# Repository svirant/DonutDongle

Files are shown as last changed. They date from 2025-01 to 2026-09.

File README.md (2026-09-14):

# Donut Dongle

**Arduino Nano based hub that connects your digital and analog console switching setup with the RetroTink 4K and/or RetroTink 5x / OSSC for Auto Profile switching** </br>

The Donut Dongle connects to a switch in a way that allows it to see which port is active. When a console powers on (auto-switching) or an input is manually selected, the Donut Dongle sends a serial command to the RetroTink 4k (or IR signal to the RT5x, OSSC) telling it to load a profile. For the RT4K, the profiles can either be defined as remote profiles; those configured in the menu for the remote buttons. Or they can be SVS profiles which are configured on the RT4K's SDcard. <br />

For details, refer to the ["How to Use"](https://github.com/svirant/DonutDongle/tree/main/README.md#how-to-use) section below.

> [!TIP]
> If DIY is not your thing. I have assembled versions for gScart/gComp and MT-VIKI/TESmart/Extron/db9 available in my [Ko-fi](https://ko-fi.com/donutswdad/shop) shop.
</br>

> [!NOTE]
> *NEW* version allows:
>   - **Alternate SVS Profile System** - allows a different set of profiles to load. Explained in the ["New IR Remote Control functionality"](https://github.com/svirant/DonutDongle#new-ir-remote-control-functionality) section below.
>   - **Fallback** - feature that allows a switch that reports having no active inputs to change profiles over to one that does.
>   - **MT-VIKI Disconnection Detection** - when an input is powered off and on, the profile is resent.
>     - **Disable MT-VIKI beeping by pressing the "#" button on its remote.**
>   - **front case buttons/remote NOW change profiles on the MT-VIKI HDMI switch.** Thanks to [Arthrimus](https://scalablevideoswitch.com/)! 
>   - **auto-switching on Extron Matrix switchers** that support DSVP. Works with RGBS/HV and HDMI/DVI signal types.
>   - **Support for older Extron Crosspoint (non plus) matrix switchers**
> <br />
> 
> <br /> Use the follow Options to enable:
> ```
> #define automatrixSW1 true  // set true for auto matrix switching on "SW1" port
> #define automatrixSW2 false // set true for auto matrix switching on "SW2" port
>
> uint8_t const ExtronVideoOutputPortSW1 = 1; // For non "Plus" Extron Matrix models, must specify video output port that connects to RT4K
> uint8_t const ExtronVideoOutputPortSW2 = 1;
> 
> uint8_t const vinMatrix[65] = {0,  // MATRIX switchers  // When auto matrix mode is enabled: (automatrixSW1 / SW2 defined above)
>                                                        // set to 0 for the auto switched input to tie to all outputs
>                                                        // set to 1 for the auto switched input to trigger a Preset
>                                                        // set to 2 for the auto switched input to tie to "ExtronVideoOutputPortSW1" / "ExtronVideoOutputPortSW2"
>                                                        //
>                                                        // For option 1, set the following inputs to the desired Preset #
>                                                        // (by default each input # is set to the same corresponding Preset #)
>                                                       
> ```
<br />

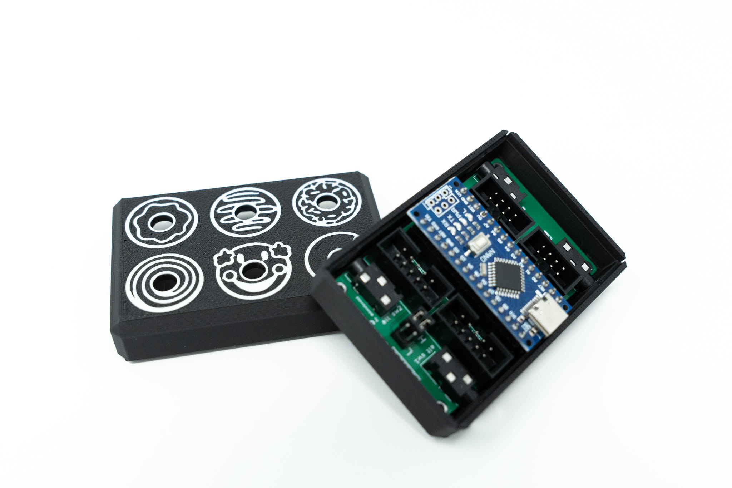
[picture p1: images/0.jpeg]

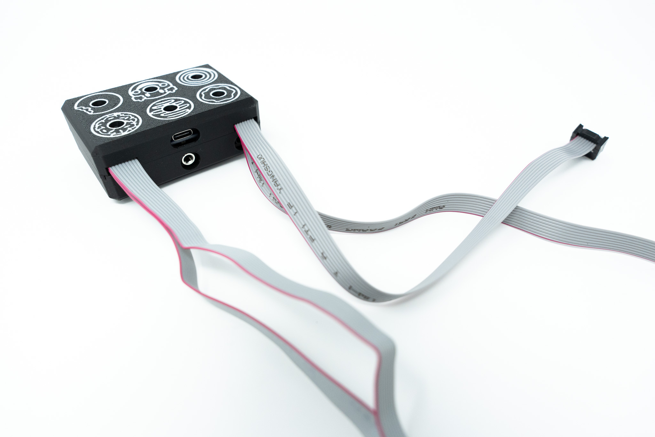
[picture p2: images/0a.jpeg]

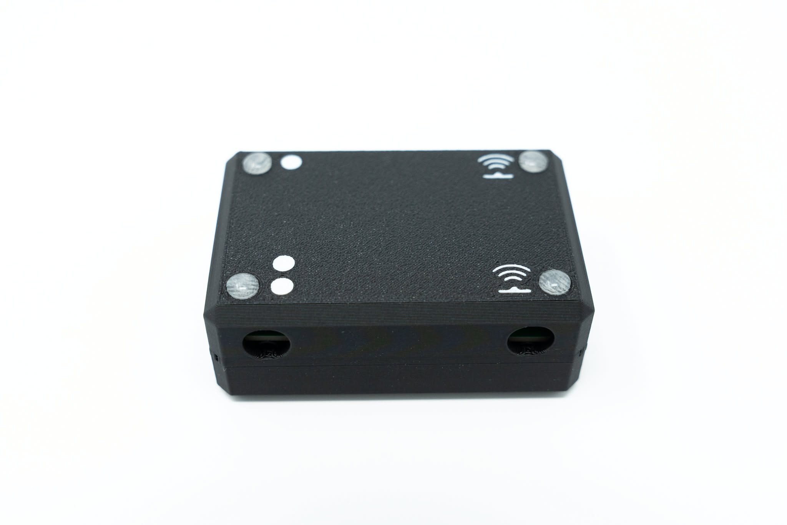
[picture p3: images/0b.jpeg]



### [More Images...](https://photos.sixteenbit.app/share/KXUwNPO2uvjenoCdj3gsQnEMd4q5h4ymUv-0fc8PItIhjA8JXHlVgPDeFnTRXM76KPM)

<br />

# Thanks to 
 - [Justin Peacock](https://byjustin.me/) for the amazing case design
 - HerraAAV3 from the RetroTink discord for the VGA Adapter case design
 - [Mike Chi](https://retrotink.com) for help with the open drain serial bits
 - [@niquallis](https://x.com/niquallis), [@UstSte](https://x.com/UstSte), and last but not least [Aru](https://x.com/CielFricker249) for beta testing

<br />

# Supported Switches
(current list, but not limited to)
| **Switch** | Supported | Notes |
| --- | --- |--- |
| MT-VIKI 8 port HDMI | yes, confirmed first hand. RT4K remote can also change inputs and profiles.  | Front case buttons and included IR remote also change profiles! **Disable MT-VIKI beeping by pressing the "#" button on its remote.** |
| TESmart 16x1 HDMI  | yes, confirmed first hand  | RT4K remote can also change inputs and profiles. |
| TESmart 8x1 HDMI  | unconfirmed, but should work, let me know! ||
| gSCARTsw / gCOMPsw | **version 5.x** confirmed by [@niquallis](https://x.com/niquallis) and [@UstSte](https://x.com/UstSte), thanks so much for your help! | Manual input selection works too! |
| Extron RGBHV sw6  | yes, confirmed first hand  | |
| Extron DXP 88 | yes, confirmed first hand | Auto-switching can be enabled in "Options" section of .ino.  Works with Presets. On SW1, Preset 1 is S1_ profile. On SW2, Preset 1 is S101_ profile, etc. <br><br>Power up the switch before connecting the DonutHole. |
| Extron CrossPoint, MVX, etc | yes, confirmed by other users | Auto-switching can be enabled for switches that supports DSVP and are RGBS/HDMI/DVI signal types. By default, works with Presets as shown in the Note above. |
| Extron CrossPoint E-series  | yes, works with Presets and Input changes | Must set ExtronVideoOutputPortSW1 / SW2 variable to output connected to RT4K |
| Extron SW4 VGA Ars | yes, confirmed by "Nobody" on the RT4K Discord |
| Otaku Games Scart 10 | Jumper moved to "L" and with required [mod](https://github.com/svirant/RT4k_HD15_serial_control/tree/main/Otaku%20Games%20Scart%20Switch) , **SVS=0; must also be set in the Otaku .ino for the DD to respond** | modded switch works on its own, but connecting through the DD is mostly useful if your Otaku mod doesn't include the buffer IC |

<br />

# Connections
  - Connect 4 switches Total
    - 2x gscart/gcomp
    - 2x Extron, 2x TESmart, or 1 of each
  - 1x usb-c port for power/programming (on Arduino Nano)
  - 1x 3.5mm "TX OUT to Retrotink 4K VGA adapter" port
  - 1x IR Emitter (required for OSSC, RT5x (RT5x must be on firmware version 3.7 or higher))
  - 1x IR Receiver (optional for better reception and IR remote customizations)
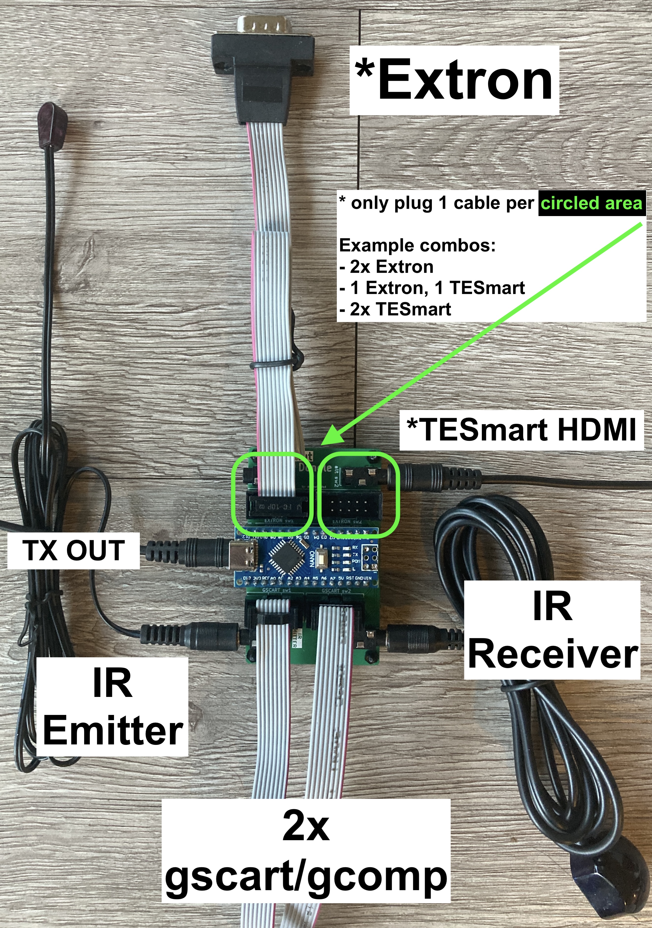
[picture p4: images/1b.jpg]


<br /><br />

# Layout Example
 - **TESmart 16x1 HDMI switch & 2x gSCART/gCOMP**
    - **VGA Passthrough adapter**
    - **TESmart adapter**
    - **gScart EXT pushpin adapter**


<br />
<br />

 - **Case closed**
   - **ribbon cables fold over and come out slots in the back of case**

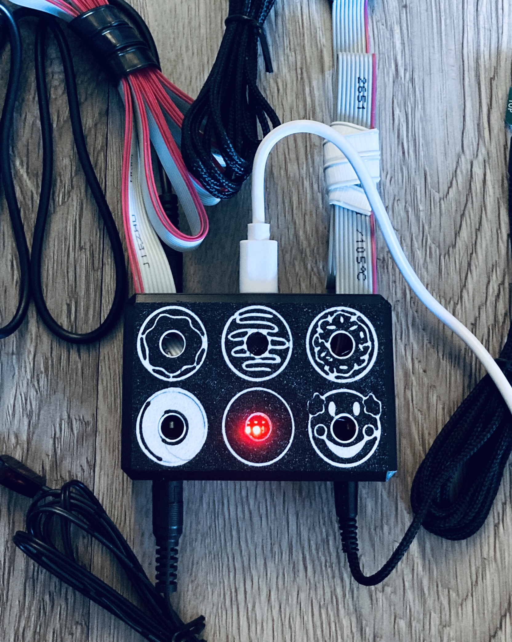
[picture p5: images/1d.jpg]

<br /><br />

# Connection Acccessories

**gscart/gcomp EXT connector (plug-n-play)**<br />
The spring pins allow it to stay "sandwiched" in place by the lid<br />
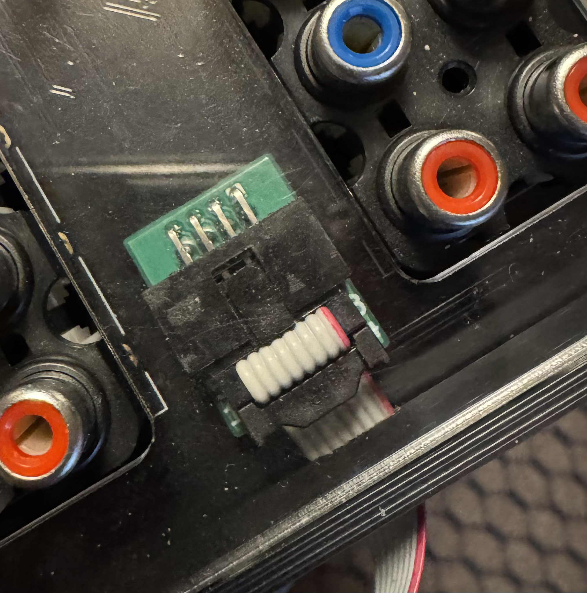
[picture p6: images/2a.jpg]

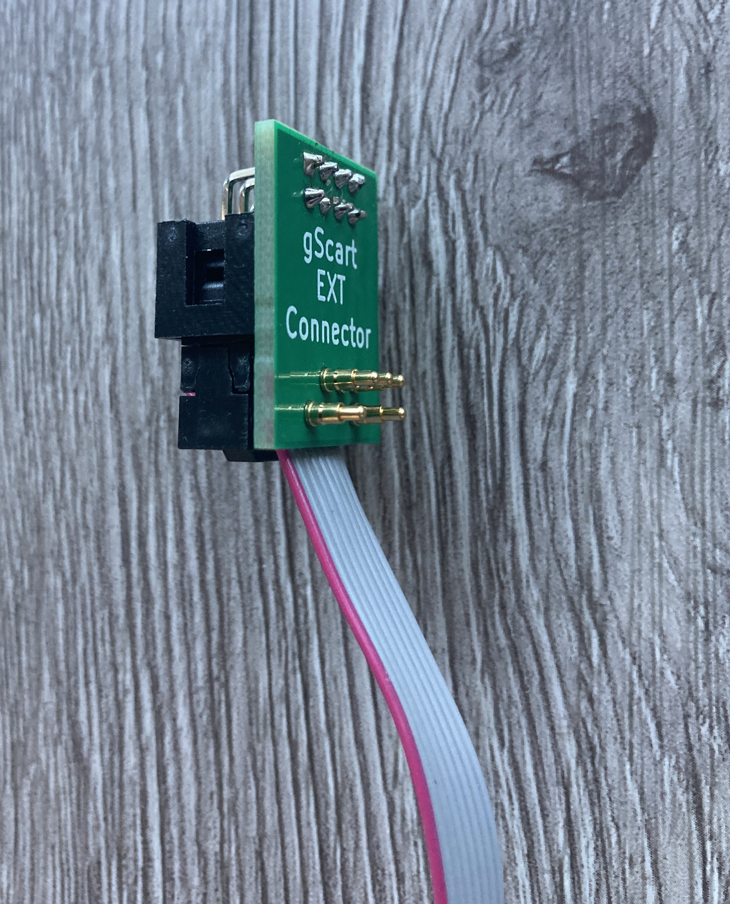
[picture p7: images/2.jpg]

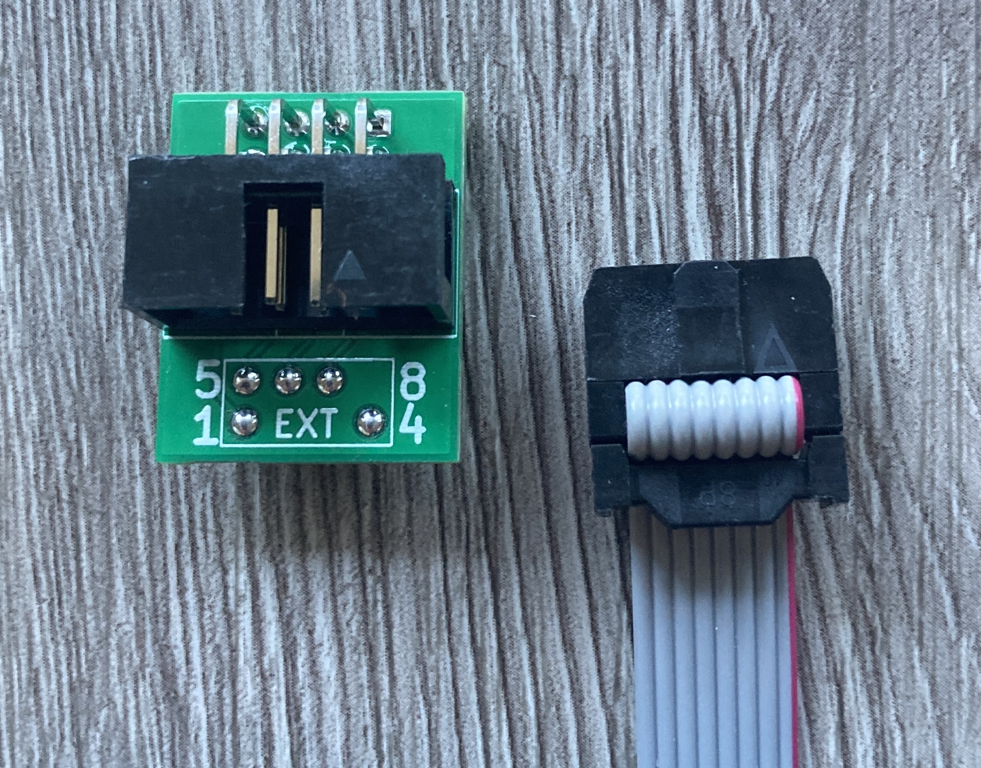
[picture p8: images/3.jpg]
<br />

**TESmart connector**<br />
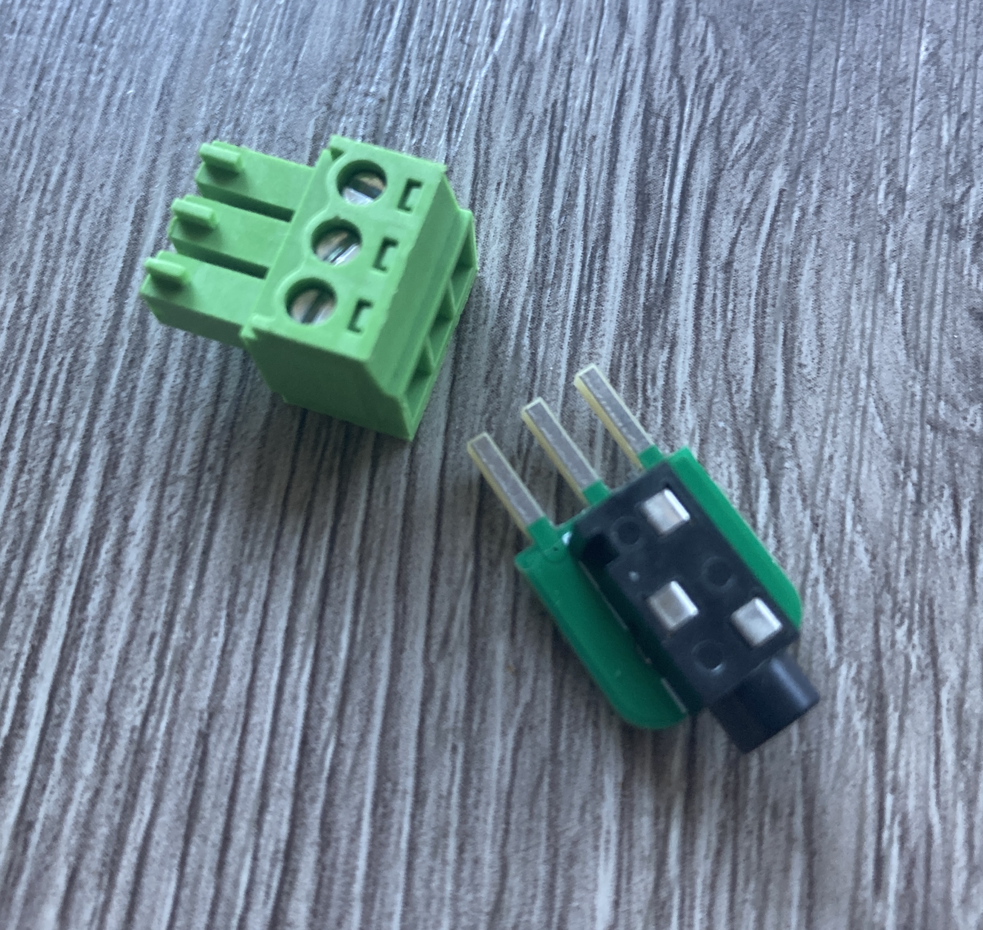
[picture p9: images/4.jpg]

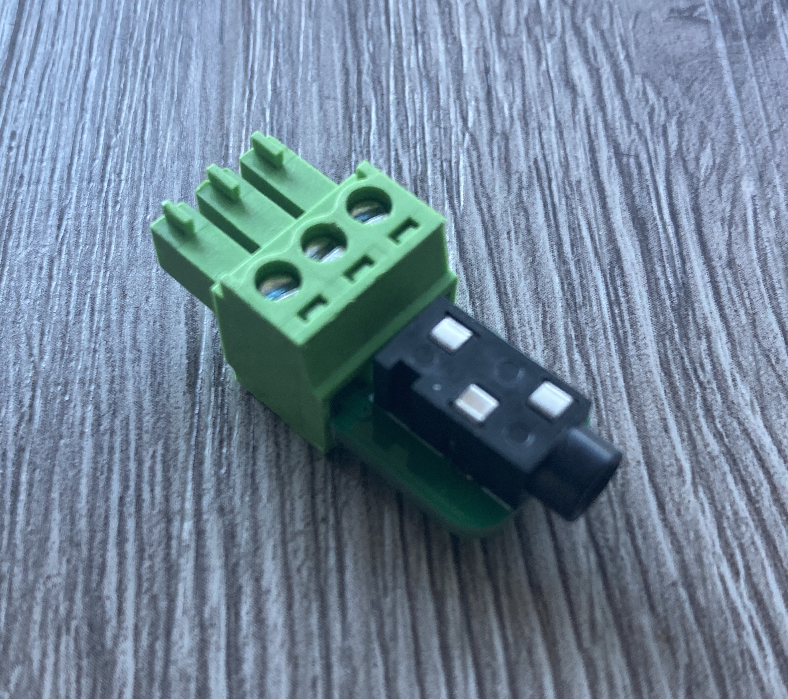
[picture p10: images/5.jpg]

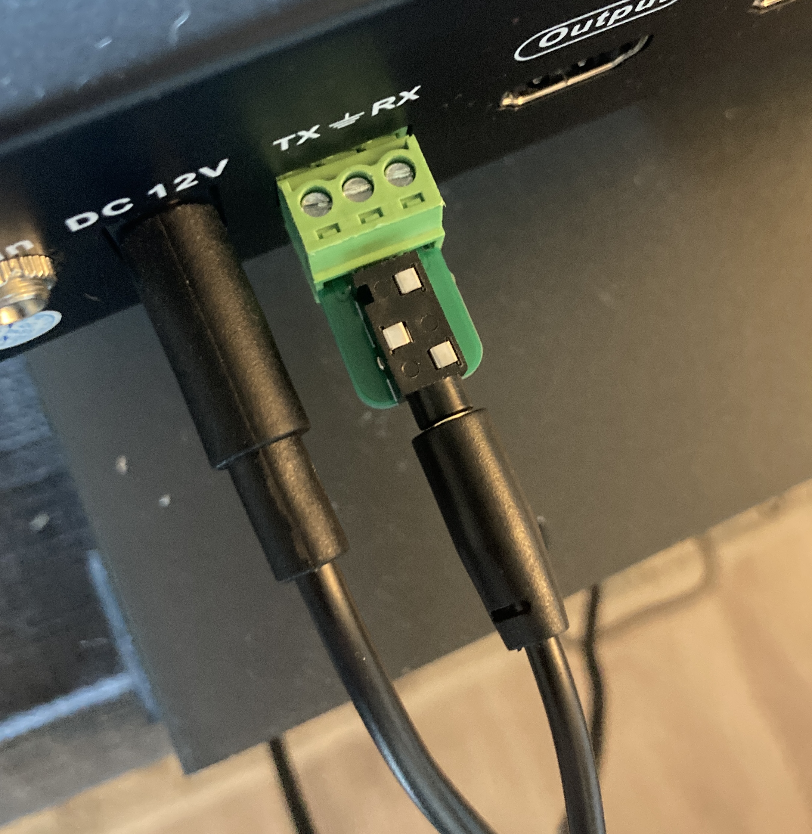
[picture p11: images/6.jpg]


**MT-VIKI / Extron / DB9 adapter**<br />
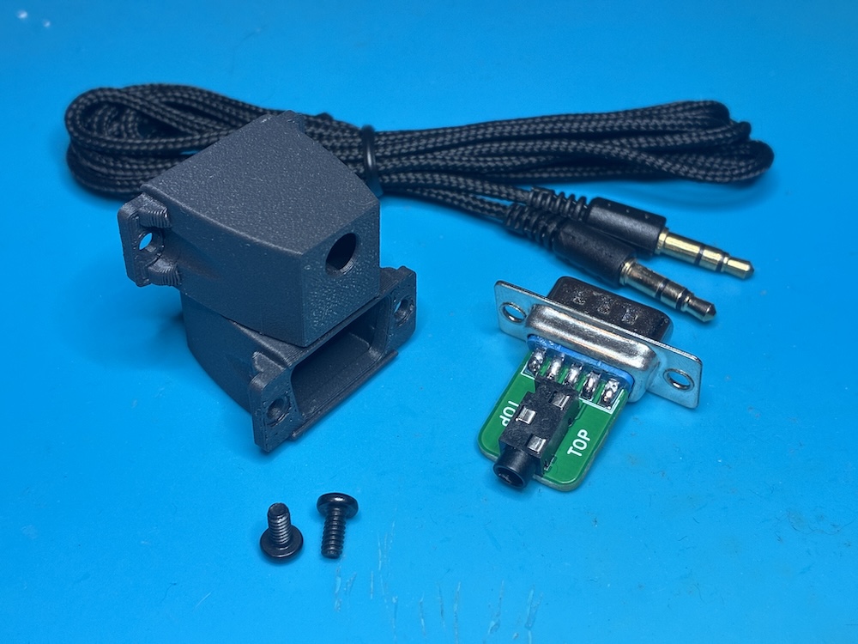
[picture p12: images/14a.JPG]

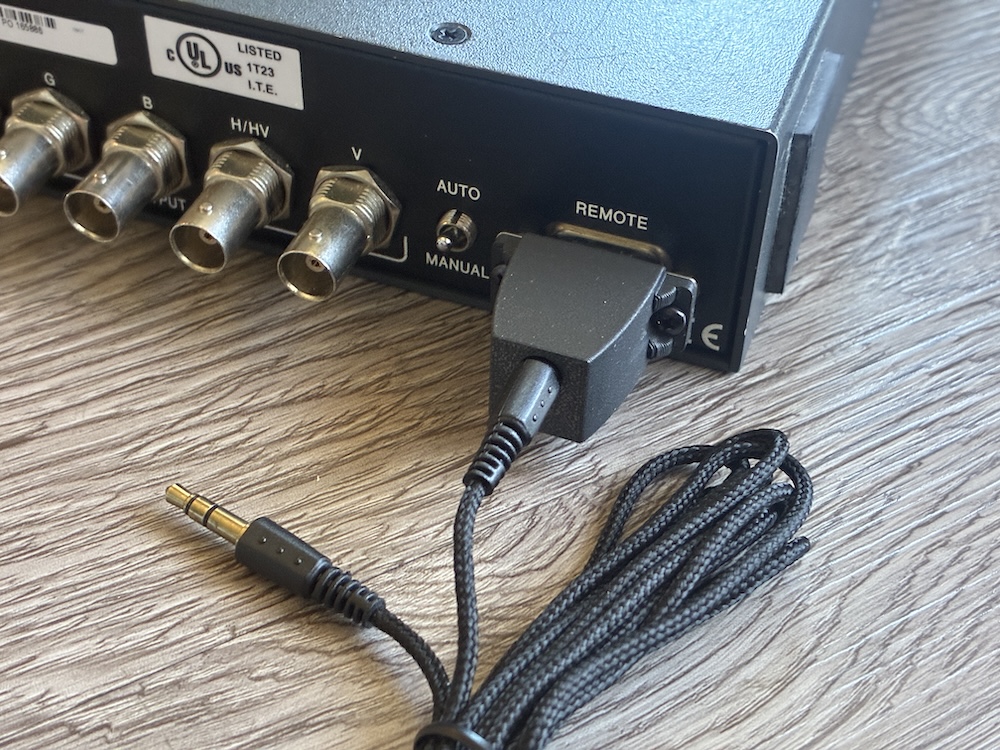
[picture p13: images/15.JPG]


**Parts listed in [BOM](https://github.com/svirant/DonutDongle/tree/main/README.md#connection-accessories) below**

**Alternate Extron connection type:**
   - **DB9 male to 3.5mm (connects to alt sw1 / alt sw2 port instead of 2x5 header)**
   - **Higher quality and much longer cord than the standard 2x5 cable**
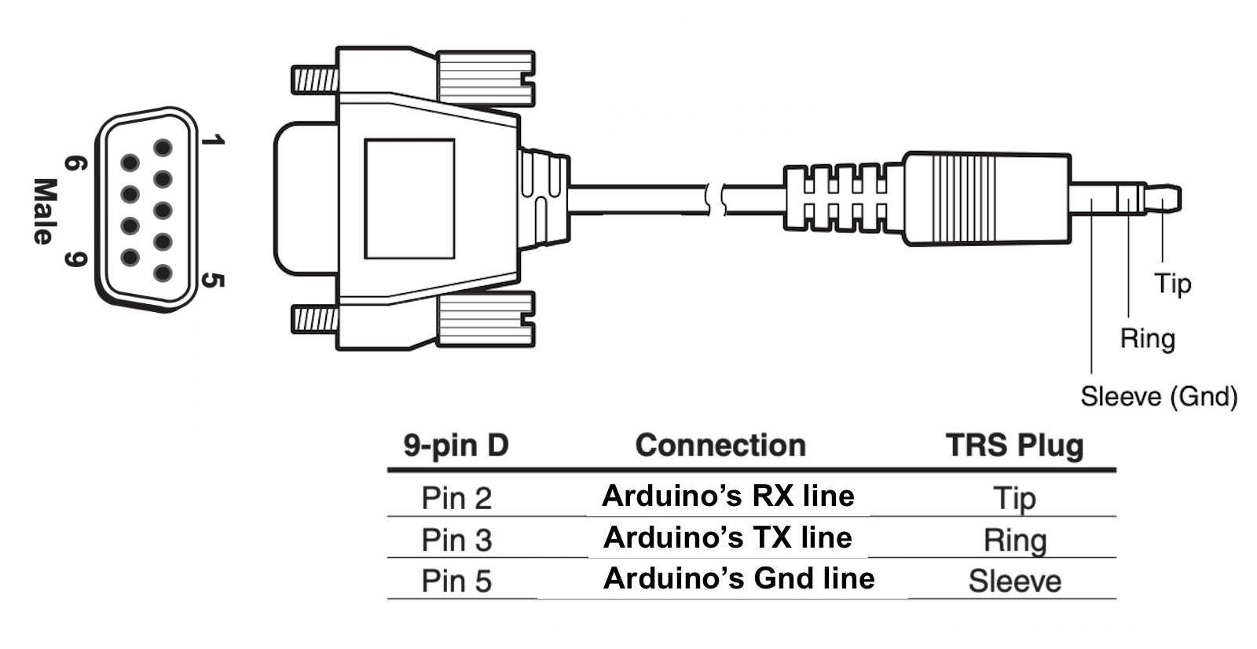
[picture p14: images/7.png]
DB9_to_TRS_wiring


----------------
# New IR Remote Control functionality
When using the optional IR Receiver, the IR reception of the RT4K can be been greatly enhanced. You can think of it as an IR repeater, but instead talks to the RT4K via Serial for solid communication. Since the Donut Dongle is in the middle, other remote features can be added such as:
 - **Alternate SVS Profiles**: Have you ever wanted to add CRT effects to all of your existing SVS profiles? Or wanted all your profiles to output at 1080p instead of 4K? With this feature you can create a set of SVS profiles that have these changes and activate the system with the remote. Pressing the "SAFE" button twice + 1 - 9 buttons will allow you to configure 9 different sets of these profiles per regular profile to load instead of the regular one you created. For example: Instead of SVS profile S1_SNES.rt4 loading, S1001_SNES.rt4 will load instead after activating with the "SAFE"x2 + 1 button. Here are some more examples so you can see the pattern used for creating these: </br>

    "SAFE"x2 + x button = Sx001_SNES-CRT.rt4, where x is the number button selected and 001 is the S1_ profile represented in 3 digits. </br>
    "SAFE"x2 + 2 button = S2001_SNES-1080p.rt4 </br>
    "SAFE"x2 + 3 button = S3001_SNES-Zoomed.rt4 </br>
    "SAFE"x2 + 4 button = S4001_SNES.rt4 </br>
    "SAFE"x2 + 5 button = S5001_SNES.rt4 </br>
    "SAFE"x2 + 6 button = S6001_SNES.rt4 </br>
    "SAFE"x2 + 7 button = S7001_SNES.rt4 </br>
    "SAFE"x2 + 8 button = S8001_SNES.rt4 </br>
    "SAFE"x2 + 9 button = S9001_SNES.rt4 </br> 

   - The name following the "\_" can be changed as well. So a name like S1001_SNES-CRT.rt4 can be used to better describe. Only the naming pattern before the "\_" is important. </br>

   - When SVS profile S2 normally would load, Sx002 would load instead where x = the number button chosen prior and 002 represents the S2 profile. S2100_NES.rt4 for example would be the 2nd Alternate profile for S100_NES.rt4. It's up to you to create these alternate sets of profiles on your SD card of course. To disable this feature and return to your normally configured profiles, press "SAFE"x2  + 10, 11, or 12 buttons on the remote.

 - SAFE button once + profile button 1 - 12 loads SVS profiles of your choosing. By default is SVS 1 - 12. Configured with auxprof[] in the Settings section of the .ino
  
 - Normally, if you power on your console before waking the RT4K, the RT4K will have not seen the profile change. Using the remote's POWER button, in this configuration, will wake the RT4K "and" resend the profile after it's finished waking.

 - AUX8 button + Power button power cycles your TV via IR Emitter. (only LG OLED CX atm, more can be added upon request)

 - AUX8 pressed twice, manually enter a SVS profile to load with the profile buttons using 1 - 9 and 10,11,12 buttons for 0. Must use 3 digits. Ex: 001 = 1, 010 = 10, etc

 - AUX8 pressed 3x will perform the standard AUX8 action
 
 - MT-ViKI 8 Port HDMI switch's inputs can be changed. Must configure "MTVir" in the options section of the .ino
    - AUX7 + button 1 - 8 for inputs 1 - 8 on "alt sw1" port (SVS profiles 1 - 8)
    - AUX8 + button 1 - 8 for inputs 1 - 8 on "alt sw2" port (SVS profiles 101 - 108)

 - TESmart 16x1 HDMI switch's inputs can changed. Must set "TESmartir" in the options section.
    - AUX7 + button 1 - 12, aux1, aux2, aux3, aux4 for inputs 1 - 16 on "alt sw1" port (SVS profiles 1 - 16)
    - AUX8 + button 1 - 12, aux1,aux2,aux3,aux4 for inputs 1 - 16 on "alt sw2" port (SVS profiles 101 - 116)

**gScart / gComp Control** (must set gctl = 1 in Options, Only supported on vers 5.x switches)

 - AUX5 button + profile button 1 - 8 button selects corresponding input on gscart sw1
    - AUX5 button + profile button 9 - 12 button to return to auto switching

 - AUX6 button + profile button 1 - 8 button selects corresponding input on gscart sw2
    - AUX6 button + profile button 9 - 12 button to return to auto switching

 - RT5x and OSSC may require a repeat of the button combos
 
 <br />

Let me know what ideas you have, and perhaps I can add them in.

**Note:** To stop the RT4K from responding twice (once from the built-in IR sensor and once from the Donut Dongle), place the included "ir_remote.txt" on the root of the SDcard. This remaps the builtin IR for every button except POWER to the RT5x remote. This way you can still use the POWER button to power on the RT4K but will stop it from responding from all other button presses.

# Ordering PCBs
PCBs for this project:
 - [Donut Dongle](https://github.com/svirant/DonutDongle/blob/main/RT4K_donut_dongle.zip)
 - [VGA Adapter](https://github.com/svirant/DonutDongle/tree/main/Adapters) (VGAPassthrough or YC2VGA)
 - (Optional) [TESmart_connector](https://github.com/svirant/DonutDongle/tree/main/Accessories)
 - (Optional) [gscart_ext_connector](https://github.com/svirant/DonutDongle/tree/main/Accessories) (works for gcomp too!)
 
There are plenty of options for PCB manufacturing but I prefer [JLCPCB](https://jlcpcb.com) (No affiliation). Using the gerber (.zip) files provided, it's easy to place an order. Below are some tips/guidelines:
- 1.0mm PCB Thickness for gscart_ext_connector.zip
- 1.6mm for all others
- For Surface Finish, "HASL(with lead)" is fine
- 4 Layer PCBs are the same cost as 2 Layer for the VGA Adapters. Because of that, the inner 2 layers are being used as ground planes for better EMI protection. Thanks to https://x.com/zaxour for the idea!
- "Remove Mark" option is now free on JLCPCB. Use it!
- All remaining default options should be fine
- Let me know if you have any questions!

# Assembly
**v1.0**<br /><br />
[Interactive HTML BOM](https://svirant.github.io/DonutDongle/images/ibom.html)

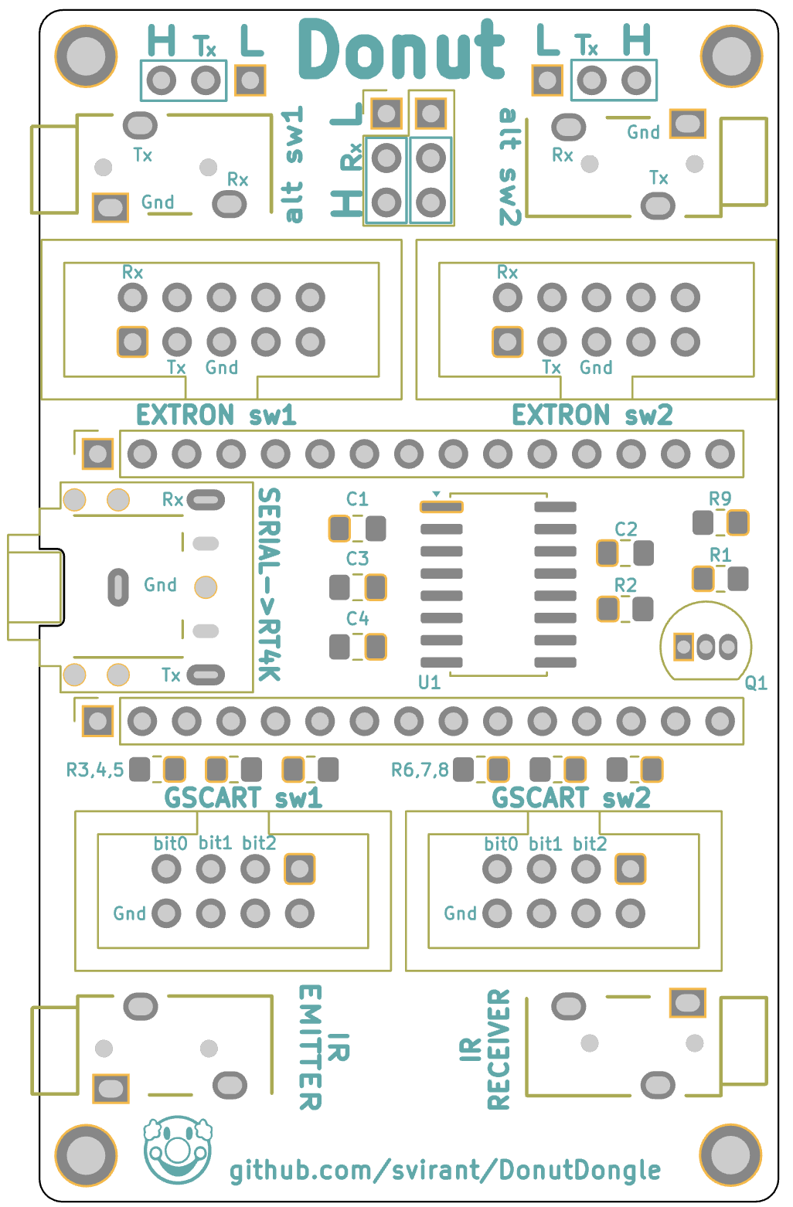
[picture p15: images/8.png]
[](https://svirant.github.io/DonutDongle/images/ibom.html)
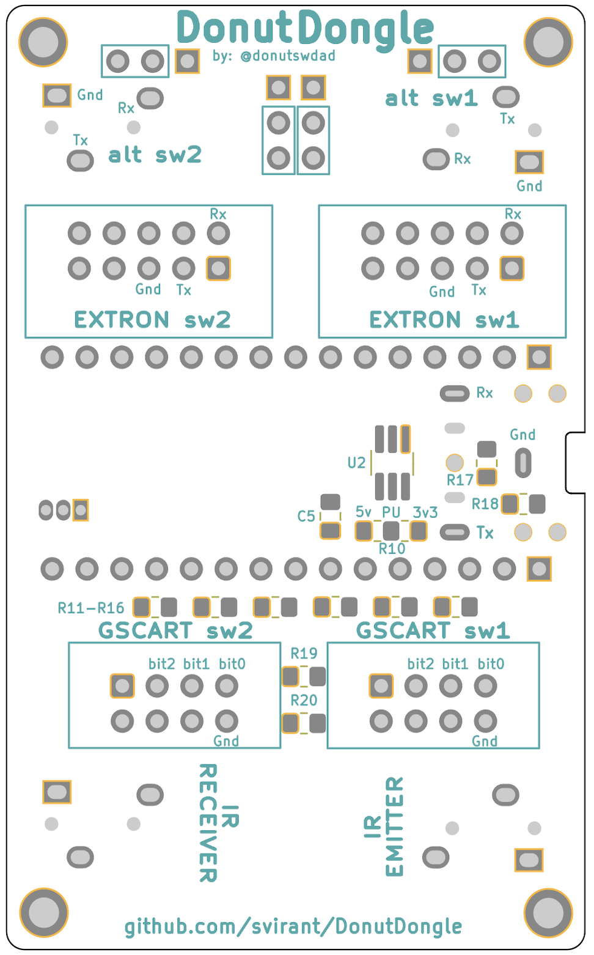
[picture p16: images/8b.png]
[](https://svirant.github.io/DonutDongle/images/ibom.html)

# (2M) baud mod
- **NOT supported with SVS connected to VGA adapter**
  - ...unless SDA/SDL trace is cut on VGA Adapter, but that disables the SVS's profile sending.
  - SVS runs at 9600 baud which conflicts with 2M regardless.
  - Extra Tx/Rx wire length of VGA cable can also cause issues. Workaround - You can cut SDA/SDL traces on the bottom of the VGA adapter to continue passing video but disables "VGA cable Serial" passthrough. (How the SVS sends profile changes)

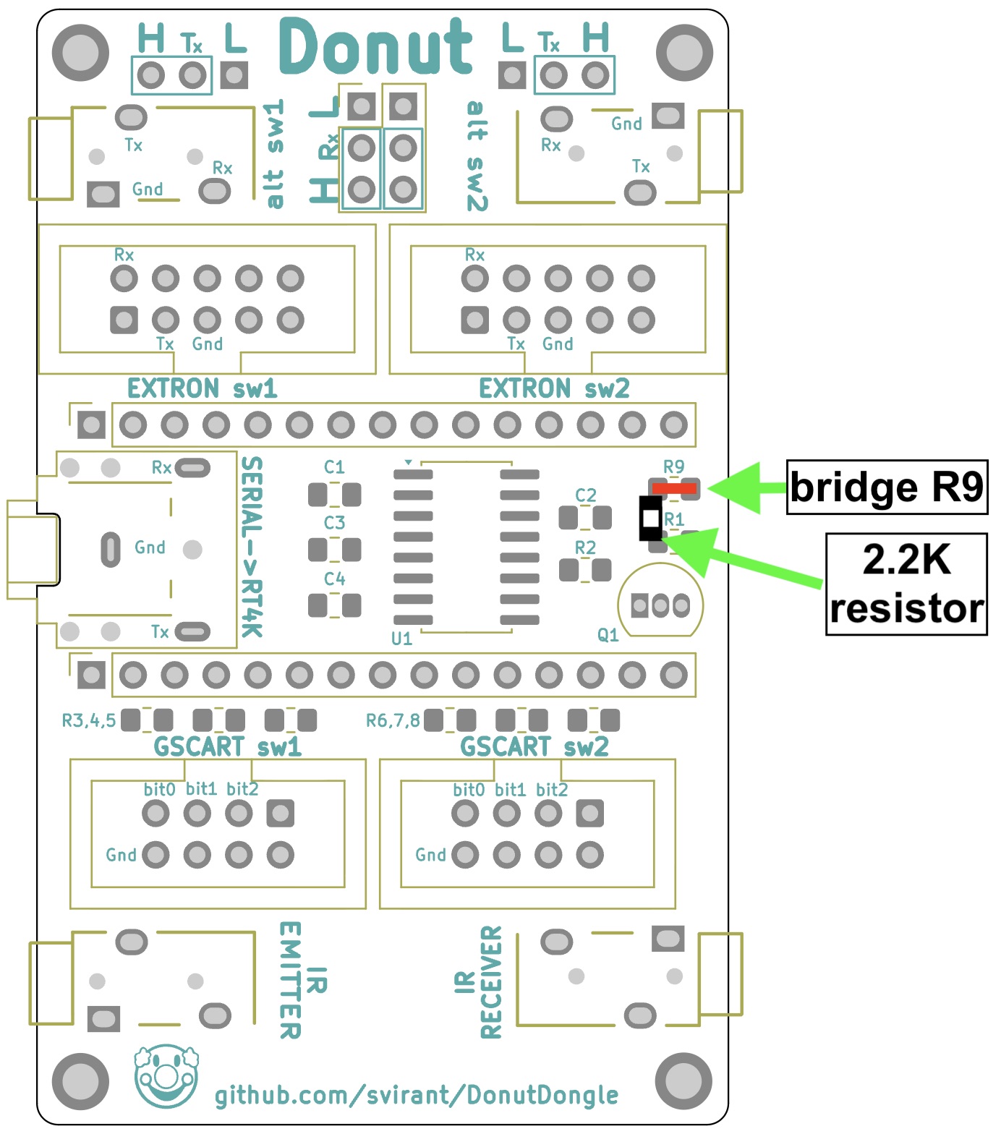
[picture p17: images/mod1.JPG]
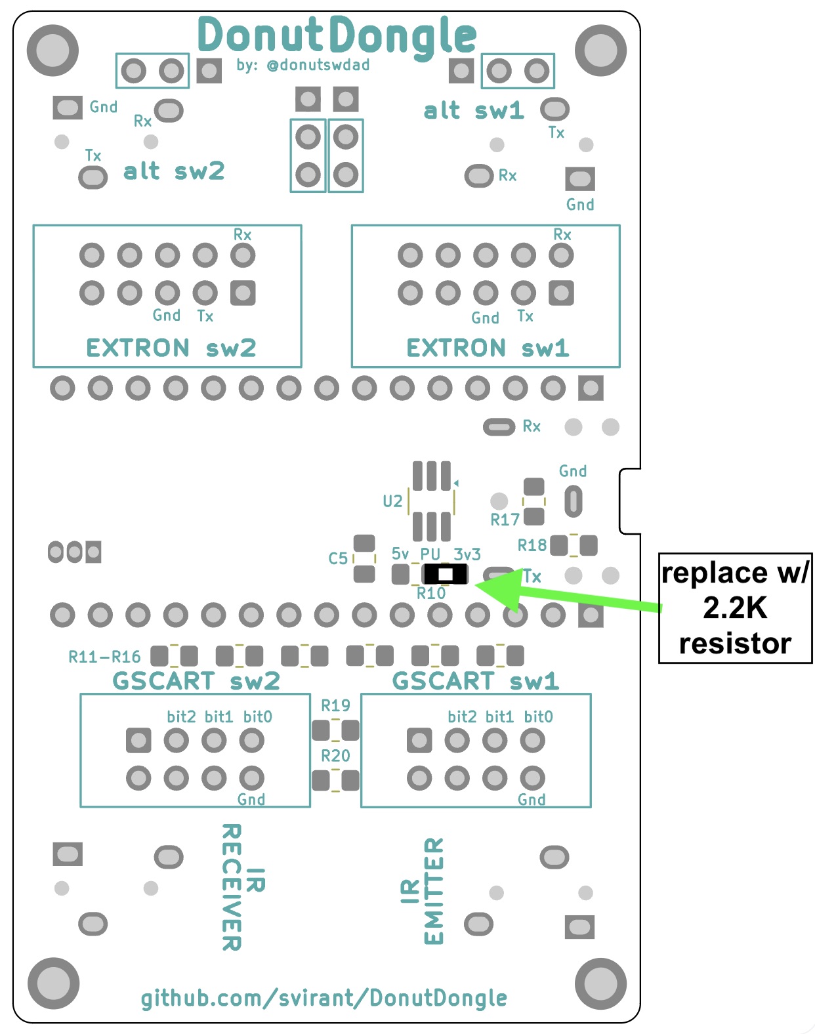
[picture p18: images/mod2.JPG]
  <br>
- Replace R10 (10K) with a 2.2K resistor
- Remove R9 and bridge pads
- Connect R1 and R9 as shown with a 2.2K resistor
<br><br>

# PCB
**v1.0**

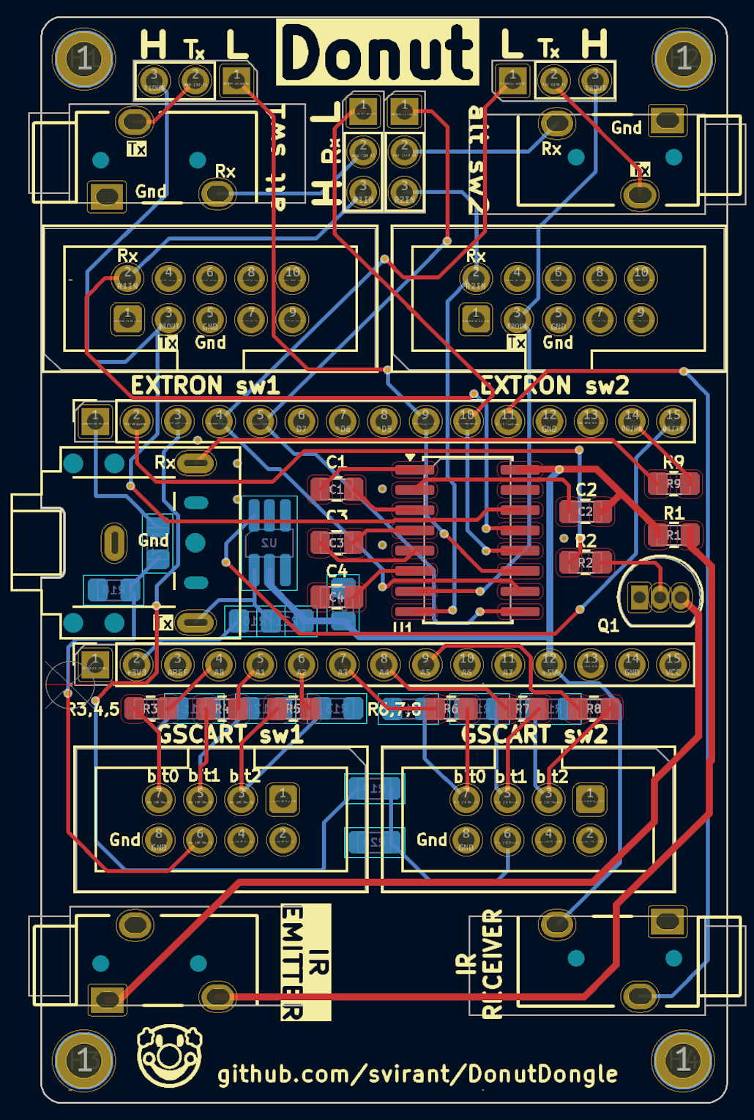
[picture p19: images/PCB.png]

<br /><br />

# Schematic
**v1.0**

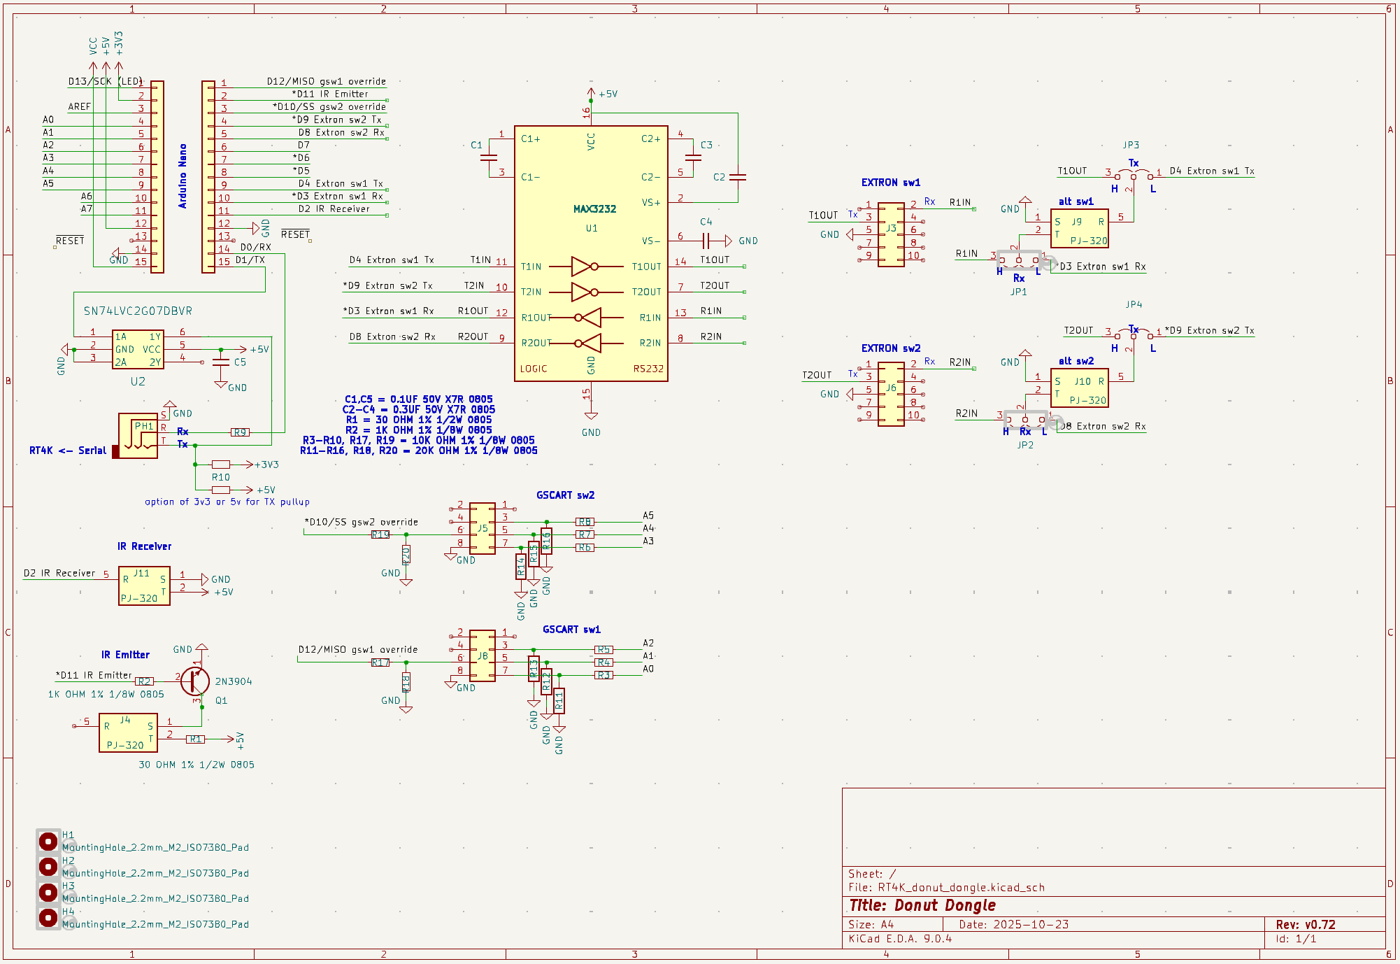
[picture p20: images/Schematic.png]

<br /><br />

## Bill of Materials (BOM)
### [- 3D Printed Dount Dongle Case](https://makerworld.com/en/models/1154283#profileId-1159282)
### [- 3D Printed VGA Adapter Case](https://github.com/svirant/DonutDongle/tree/main/Adapters) [Courtesy of HerraAAV3 on the RetroTink Discord]
### [- Digikey shared list](https://www.digikey.com/en/mylists/list/53XEHTQZJK)
### [- AliExpress wish list](https://www.aliexpress.com/p/wish-manage/share.html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)
<br />

* **Donut Dongle PCB**

| **Qty** | Designation | Part |  Link  |  Notes |
| --- | --- |--- |--- |--- |
| 2  | C1,C5 | 0.1 uf / 100nf 50V X7R 0805 Capacitor| [Digikey](https://www.digikey.com/en/products/detail/yageo/CC0805KRX7R9BB104/302874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) | |
| 3  | C2-C4 | 0.33 uf / 330nf 50V X7R 0805 Capacitor| [Digikey](https://www.digikey.com/en/products/detail/samsung-electro-mechanics/CL21B334KBFNNNE/3886781) | |
| 1  | R1 | 30 OHM 1% 1/2W 0805 Resistor | [Digikey](https://www.digikey.com/en/products/detail/panasonic-electronic-components/ERJ-P06F30R0V/9811718) | |
| 1  | R2 | 1K OHM 1% 1/8W 0805 Resistor | [Digikey](https://www.digikey.com/en/products/detail/yageo/RC0805FR-071KL/727444) | |
| 10  | R3 - R10, R17, R19 | 10K OHM 1% 1/8W 0805 Resistor | [Digikey](https://www.digikey.com/en/products/detail/yageo/AC0805FR-0710KL/2827834) | |
| 8  | R11 - R16, R18, R20 | 20K OHM 1% 1/8W 0805 Resistor | [Digikey](https://www.digikey.com/en/products/detail/yageo/RC0805FR-0720KL/727720) | |
| 1  | Q1 | 2N3904 NPN Transistor | [AliExpress](https://www.aliexpress.us/item/3256806623522970.html) | |
| 1  | U1 | MAX3232 SOP-16 RS-232 Interface IC | [AliExpress](https://www.aliexpress.us/item/3256807314260762.html) | |
| 1  | U2 | IC BUF NON-INVERT 5.5V SOT23-6 | [Digikey](https://www.digikey.com/en/products/detail/texas-instruments/SN74LVC2G07DBVR/486427) or [alternate](https://www.digikey.com/en/products/detail/umw/SN74LVC2G07DBVR/24889644)| |
| 1  | PH1 | PJ-307 3.5mm Stereo Jack | [AliExpress](https://www.aliexpress.us/item/3256805624175150.html) | |
| | |  or **1x** 3.5mm Audio Jack Socket | [AliExpress](https://www.aliexpress.us/item/2251832685563184.html) | Like the PJ-307 but missing the inner 2 poles which arent needed anyways |
| 4  | J4,J9-11 | PJ-320 3.5MM Headphone Jack Audio Video Female | [AliExpress](https://www.aliexpress.us/item/3256807448104402.html) | Color: PJ-320B DIP | 
| 2  | J3,J6 | 2x5 Pin Double Row 2.54mm Pitch Straight Box Header | [AliExpress](https://www.aliexpress.us/item/3256805177947724.html) | (Color: STRAIGHT TYPE, Pins: 10PCS DC3-10Pin) |
| 2  | J5,J8 | 2x4 Pin Double Row 2.54mm Pitch Straight Box Header | [AliExpress](https://www.aliexpress.us/item/3256805177947724.html) | (Color: STRAIGHT TYPE, Pins: 10PCS DC3-8Pin) |
| 1  | (optional) | 3.5mm CHF03 1.5 Meters IR Infrared Remote Emission Cable | [AliExpress](https://www.aliexpress.us/item/3256805962345169.html) | required for OSSC, RT5X (must be firmware version 3.7+) |
| 1  | (optional) | 3.5mm Infrared Remote Control Receiver Extension Cable | [AliExpress](https://www.aliexpress.us/item/2251832741040177.html) | required for [New IR Remote Control functionality](https://github.com/svirant/DonutDongle?tab=readme-ov-file#new-ir-remote-control-functionality) |
| 2  | H1,H2 | 2.54mm Pitch Single Row Female 15P Header Strip | [AliExpress](https://www.aliexpress.us/item/3256801232229618.html) | |
| 1  | | Any 3.5mm / aux / stereo / trs / cable | [AliExpress](https://www.aliexpress.us/item/2255799962255486.html) | |
| 1  | | usb-c cable for Arduino power & initial programming | [AliExpress](https://www.aliexpress.us/item/3256806983355947.html) | |
| 1  | | Arduino Nano type c | Support [RetroRGB!](https://amzn.to/4gnHqN4) | Make sure the headers and esp the 2x3 pins are not soldered. |
| 1  | JP2 | 2x3 Pin Double Row 2.54mm Pitch Header | | Use the one that comes with the Arduino Nano. Jumper "H" for all switches unless instructed otherwise. |
| 2  | JP3,4 | 1x3 Pin Single Row 2.54 Pitch Header | | Dont buy two 1x3. Find any single row header and break off two 1x3 sections. Jumper "H" for all switches unless instructed otherwise. |
| 4  | | 2.54mm Jumper | [AliExpress](https://www.aliexpress.us/item/2255800354403384.html) | You can also just solder blob "H". "L" jumper setting has only 1 use case atm. |

* **Switch connection Cables**

| **Qty** | Switch Type | Part |  Link  |  Notes |
| --- | --- |--- |--- |--- |
| 1 or 2 | **TESmart HDMI** | Any 3.5mm / aux / stereo / trs / Cable | [AliExpress](https://www.aliexpress.us/item/2255799962255486.html) | strip 1 end to expose red(Rx)/white(Tx)/gnd wires for the green screw clamp OR use the TESmart_connector shown below|
| 1 or 2 | **GscartSW/GCompSW** | 2x4 Pin Double Row 2.54 Pitch Angled Box Header | [AliExpress](https://www.aliexpress.us/item/3256805177947724.html?) | (Color: RIGHT ANGLE TYPE, Pins: 10PCS DC3 8Pin), Solders onto EXT port. Or use the gscart_ext_connector shown below.  |
|1 or 2 | **GscartSW/GCompSW** | 2x4 Pin Female Header Ribbon Cable | [AliExpress](https://www.aliexpress.us/item/3256804576275377.html?) | (Pins: 2x4Pin, Color: Any length) |
| 1  | **Extron** | 2 Port DB9 to 2x5 Pin Female Header Ribbon Cable | [AliExpress](https://www.aliexpress.us/item/3256807472891897.html) | |
| | | or **2x** DB9 Male to 3.5mm Male Serial RS232 Cable 6feet | [Amazon](https://www.amazon.com/LIANSHU-DC3-5mm-Serial-RS232-Cable/dp/B07G2ZL3SL/) | "MUST" be wired as so: [DB9 Male Pin 5 -> Sleeve, DB9 Male Pin 2 -> Tip, DB9 Male Pin 3 -> Ring](/images/7.png) |
| | | **or** make your own connectors in the "[Connection Accessories](https://github.com/svirant/DonutDongle?tab=readme-ov-file#connection-accessories-optional)" section below. | | |

### At least 1 of the following [VGA adapters](https://github.com/svirant/DonutDongle/tree/main/Adapters) is required:

* **YC2VGA w/ Serial Tap v2: (enhanced s-video and composite as a bonus)**

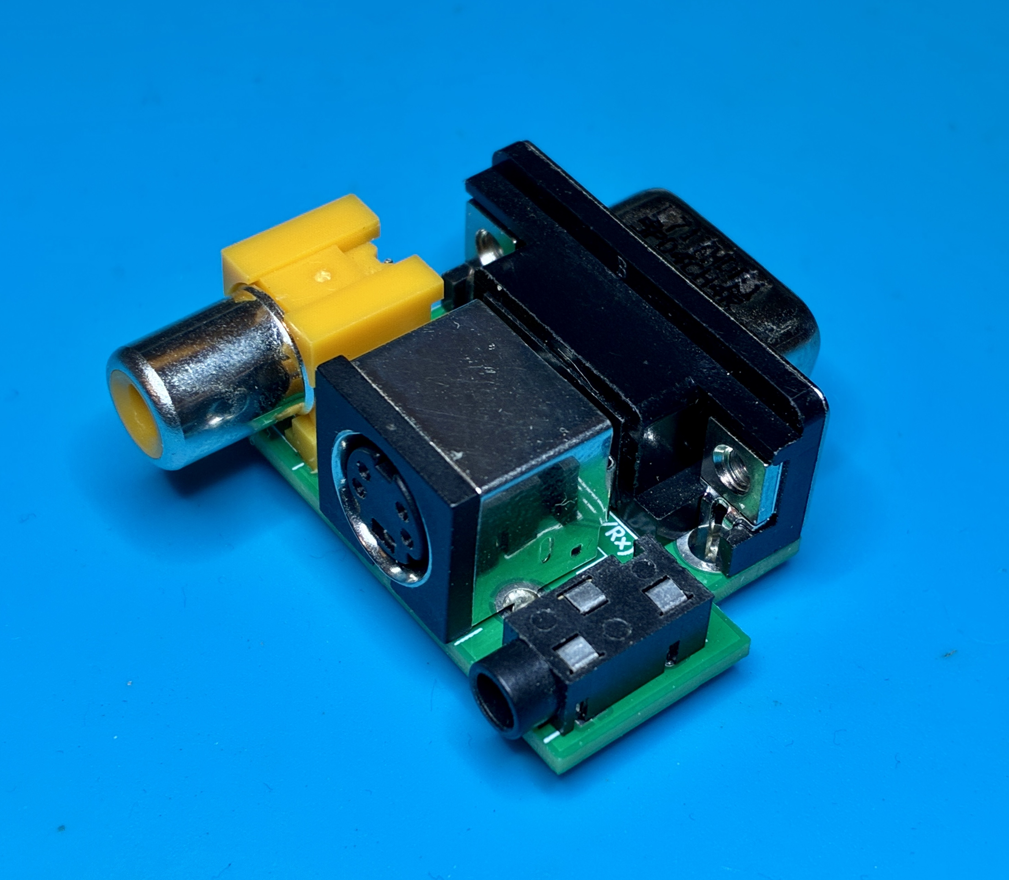
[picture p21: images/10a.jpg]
<br />

| **Qty** | Part |  Link  |  Notes |
| --- | --- |--- |--- |
| 1  | Yellow RCA Composite jack | [AliExpress](https://www.aliexpress.us/item/3256805949533421.html) | (Color: Yellow) |
| 1  | S-Video jack | [AliExpress](https://www.aliexpress.us/item/3256804041313042.html) | (Color: A 4Pin) |
| 1  | PJ-320 3.5MM Headphone Jack Audio Video Female | [AliExpress](https://www.aliexpress.us/item/3256805995568762.html) | (Color: 10PCS PJ-320) |
| 1  | VGA Male Connector [L717HDE15PD4CH4R-ND] | [Digikey](https://www.digikey.com/en/products/detail/amphenol-cs-commercial-products/L717HDE15PD4CH4R/4886543) | |
 
* **VGA Passthrough w/ Shared Serial Tap:**
   - Confirmed compatible with the Scalable Video Switch and it's auto profiles.

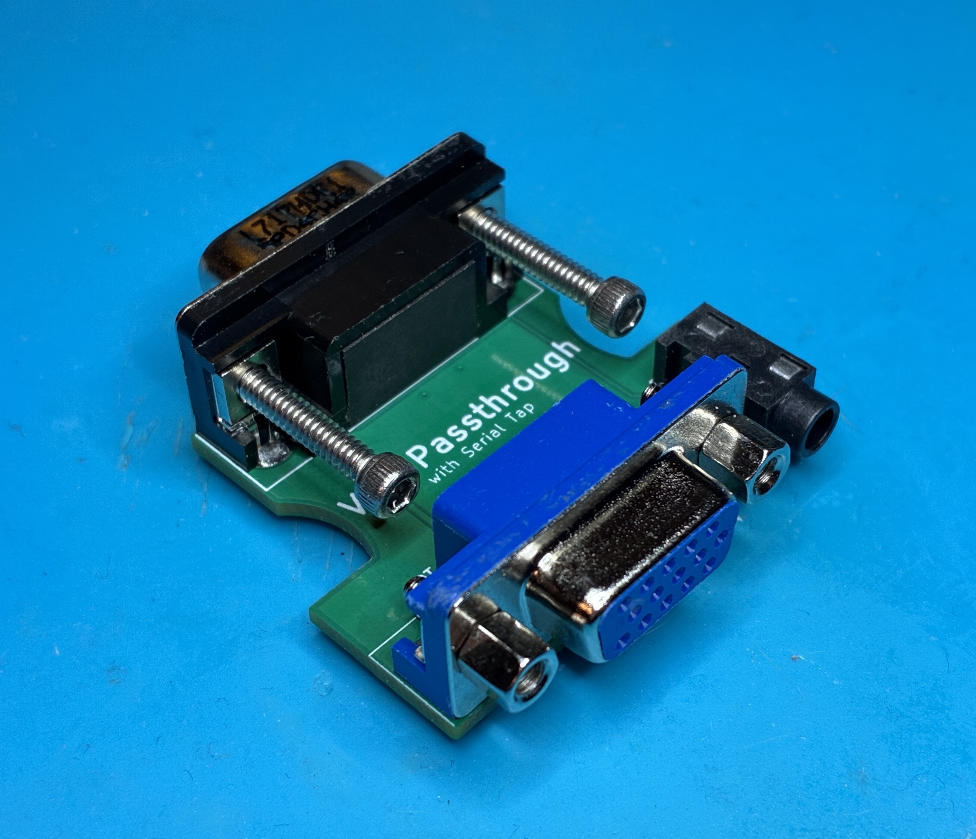
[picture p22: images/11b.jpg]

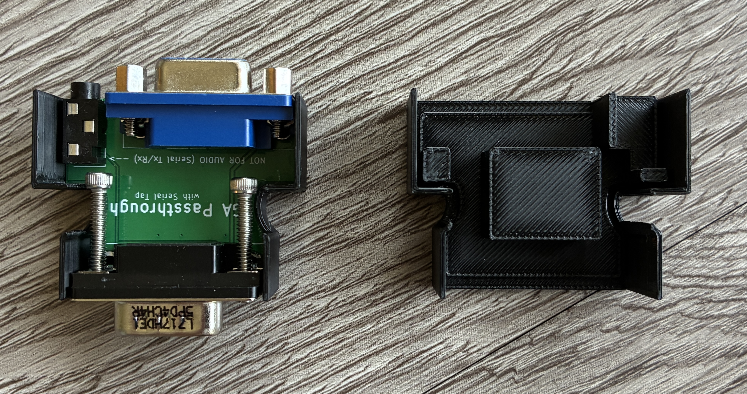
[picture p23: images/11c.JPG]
<br />
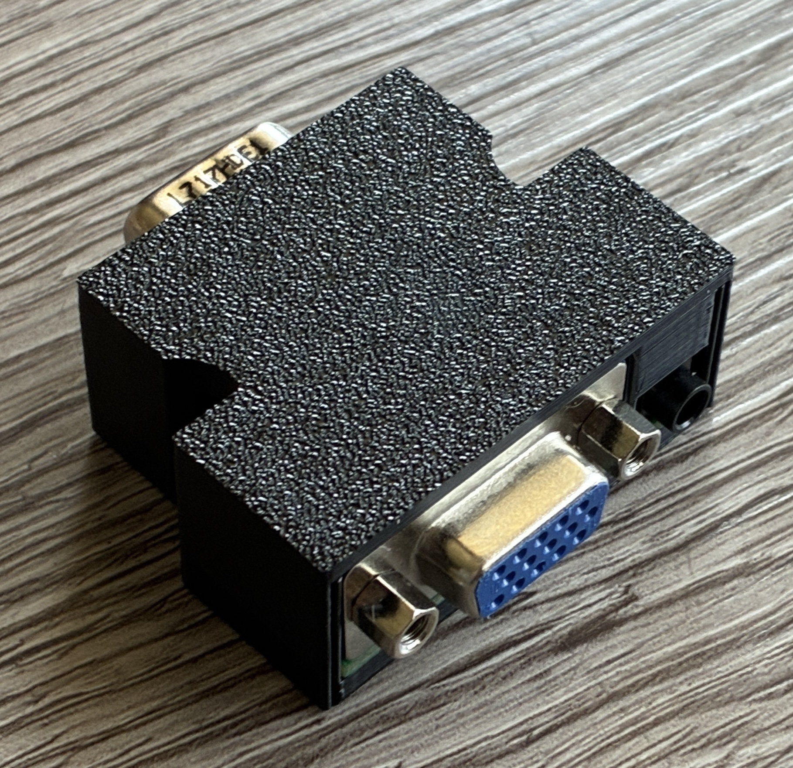
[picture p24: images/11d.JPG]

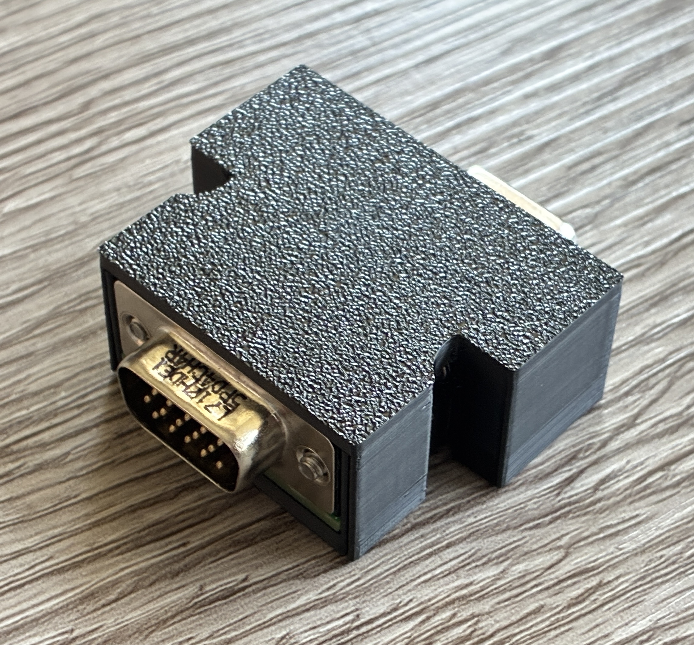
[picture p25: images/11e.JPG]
<br />

| **Qty** | Part |  Link  |  Notes |
| --- | --- |--- |--- |
| 1 | VGA Male Connector [L717HDE15PD4CH4R-ND] | [Digikey](https://www.digikey.com/en/products/detail/amphenol-cs-commercial-products/L717HDE15PD4CH4R/4886543) | |
| 1 | VGA Female Connector | [AliExpress](https://www.aliexpress.us/item/3256807197056325.html) | (Color: DB15 3.08) |
| 1 | PJ-320 3.5MM Headphone Jack Audio Video Female | [AliExpress](https://www.aliexpress.us/item/3256805995568762.html) | (Color: 10PCS PJ-320) |
| 2 | #4-40 x 3/4" screw (optional) | [Ebay](https://www.ebay.com/itm/222577369468) | |

  ### [Connection Accessories](https://github.com/svirant/DonutDongle/tree/main/Accessories) (optional)

  * **gscart/gcomp EXT connector**

| **Qty** | Part |  Link  |  Notes |
| --- | --- |--- |--- |
| 1 | 2x4 Pin Double Row 2.54 Pitch Angled Box Header | [AliExpress](https://www.aliexpress.us/item/3256805177947724.html?) | (Color: RIGHT ANGLE TYPE, Pins: 10PCS DC3 8Pin) |
| 6 | Pogo-Pin | [Digikey](https://www.digikey.com/en/products/detail/mill-max-manufacturing-corp/0906-1-15-20-75-14-11-0/1147049) | |
   
  * **TESmart connector**

 | **Qty**    | Part |  Link  |  Notes |
| ------------- | ------------- |------------- |------------- |
| 1 | PJ-320 3.5MM Headphone Jack Audio Video Female | [AliExpress](https://www.aliexpress.us/item/3256805995568762.html) | (Color: 10PCS PJ-320) |

  * **MT-VIKI / Extron / DB9 connector**

 | **Qty**    | Part |  Link  |  Notes |
| ------------- | ------------- |------------- |------------- |
| 1 | PJ-320 3.5MM Headphone Jack Audio Video Female | [AliExpress](https://www.aliexpress.us/item/3256805995568762.html) | (Color: 10PCS PJ-320) |
| 1 | DB9 Male connector | [AliExpress](https://www.aliexpress.us/item/3256805749759770.html?) | (Color: Male head) |
| 2 | #4-40 1/4" pan head screw | [Amazon](https://www.amazon.com/dp/B00F34USTG?) | |

  -----------
# Programming an Arduino Nano
I recommend the [Official Arduino IDE and guide](https://www.arduino.cc/en/software/) if you're unfamiliar with Arduinos. All .ino files used for programming are listed above. The following Libraries will also need to be added in order to Compile successfully.<br />
- **Libraries:**
  - <IRremote.hpp> "IRremote" available through the built-in Library Manager under "Tools" -> "Manage Libraries..."
  - <AltSoftSerial.h>  Follow these steps to add AltSoftSerial.h
    - Goto https://github.com/PaulStoffregen/AltSoftSerial
    - Click the GREEN "<> Code" box and "Download ZIP"
    - In Arduino IDE; goto "Sketch" -> "Include Library" -> "Add .ZIP Library"
   
## Steps to program the Donut Dongle
 - 1 - Click the green "<> Code" button above and "Download ZIP".
 - 2 - Extract the .zip file and open up the "Donut_Dongle.ino" file in the Arduino IDE. It will ask if you would like to move this file inside a folder, select OK.
 - 3 - With the source code now open, select "Tools" -> "Board" -> "Arduino AVR Boards" -> "Arduino Nano"
 - 4 - Connect the Donut Dongle device to your PC or Mac using the usb-c cable. You should see an LED light up when connected.
 - 5 - With the Donut Dongle now connected, select it's "port" by going to "Tools" -> "Port", and select the port that starts with "/dev/cu.usbserial-" (on Mac) or "COM" if on PC.
 - 6 - From the menu at the top, select "Sketch" -> "Verify/Compile". If everything is setup properly, you should see a message in the bottom corner saying "Done compiling".
 - 7 - Now select "Sketch" -> "Upload". You should see the LEDs on the Donut Dongle flicker and a message that says "Done uploading." if successful.
   - If you get errors, see the section below about changing the "Bootloader" type.
 - 8 - Disconnect the usb-c cable from your computer and give it a whirl! You can repeat these steps in the future to make any other changes or update if a newer firmware is ever released.
 - 9 - It's also best practice when unplugging/reconnecting cables to the Donut Dongle, that you do so with the power disconnected. 
<br>

  -----------
# How to Use
- Make sure **"Auto Load SVS"** is **"On"** under the RT4K Profiles menu.  
- The RT4K checks the **/profile/SVS** subfolder for profiles and need to be named: **S\<input number>_\<user defined>.rt4**  For example, SVS input 2 would look for a profile that is named S2_SNES.rt4.  If there’s more than one profile that fits the pattern, the first match is used.

- Check the RT4K Diagnostic Console for Serial commands being received as confirmation.

  -----------
# Troubleshooting
 - When (un)plugging aux cables from "alt sw1" or "alt sw2" ports make sure Donut Dongle power is disconnected. Sometimes the onboard MAX3232 chip can lock up if this is not done.
   - To fix lockup, power off switch and DD (Donut Dongle). Disconnect/reconnect aux cable from DD and power up switch first, then DD last.
  
 - Some Arduino Nanos come with an Old Bootloader and won't Upload unless specified. **If you get errors** when trying to upload, swap to this option as a possible fix.

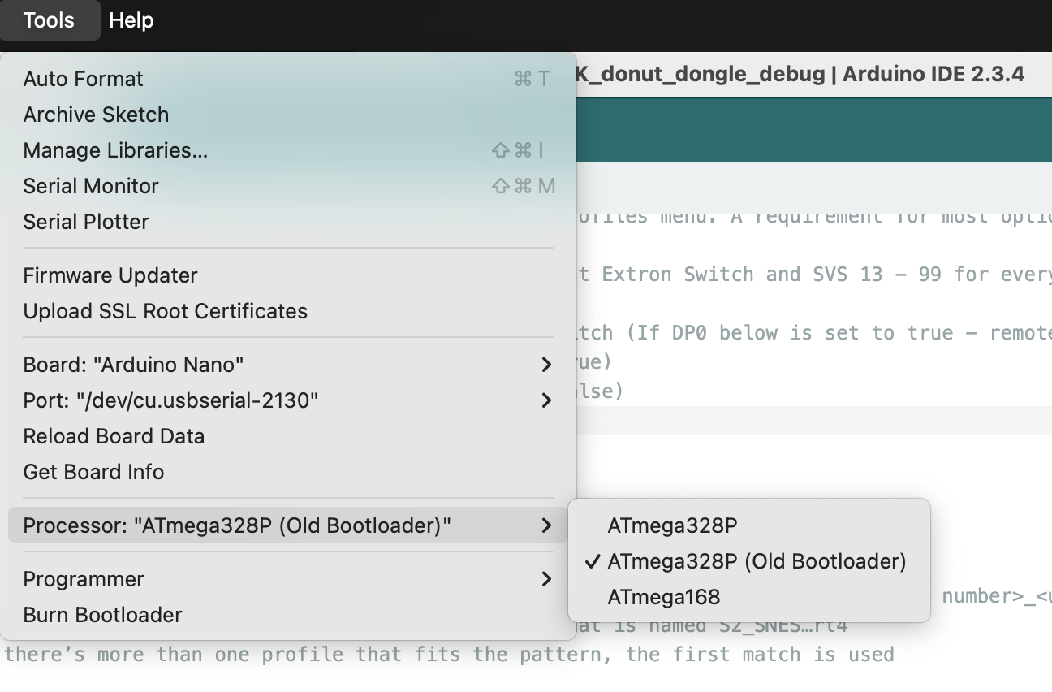
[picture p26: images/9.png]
bootloader

  
  -----------
## SVS Profile numbering scheme

| **SVS = 1 (default)** | **Profile #** | Notes |
|---|---|---|
| Extron sw1 / alt sw1 | 1 -  99 | also for TESmart, MT-ViKi, Otaku Games Scart 10 devices|
| Extron sw2 / alt sw2 | 101 - 199 | also for TESmart, MT-ViKi, Otaku Games Scart 10 devices |
| GSCART sw1 | 201 - 208 | |
| GSCART sw2 | 209 - 216 | |

Remote Button Profiles are **not** used when **SVS=1**

<br />

| **SVS = 0** | **Profile #** | Notes |
|---|---|---|
| Extron sw1 / alt sw1 | 13 -  99 | also for TESmart, MT-ViKi, Otaku Games Scart 10 devices|
| Extron sw2 / alt sw2 | 101 - 199 | also for TESmart, MT-ViKi, Otaku Games Scart 10 devices |
| GSCART sw1 | 201 - 208 | |
| GSCART sw2 | 209 - 216 | |

Remote Button Profiles **1-12** are used for Extron sw1 when **SVS=0**

<br />

| **SVS = 2** | **Profile #** | Notes |
|---|---|---|
| Extron sw1 / alt sw1 | 1 -  99 | also for TESmart, MT-ViKi, Otaku Games Scart 10 devices|
| Extron sw2 / alt sw2 | 101 - 199 | also for TESmart, MT-ViKi, Otaku Games Scart 10 devices |
| GSCART sw1 | N/A | |
| GSCART sw2 | 213 - 216 | inputs 5-8 |

Remote Button Profiles **1-12** are used for GSCART sw1 inputs **1-8** and GSCART sw2 inputs **1-4** when **SVS=2**

<br />

----------------

The following is from the .ino file itself. Refer to it directly for all **Advanced Options**.
```
/*
////////////////////
//    OPTIONS    //
//////////////////
*/

uint8_t const debugE1CAP = 0; // line ~495
uint8_t const debugE2CAP = 0; // line ~768
uint8_t const debugState = 0; // line ~432

uint16_t const offset = 0; // Only needed for multiple Donut Dongles (DD). Set offset so 2nd,3rd,etc boards don't overlap SVS profiles. (e.g. offset = 300;) 
                      // MUST use SVS=1 on additional DDs. If using the IR receiver, recommended to have it only connected to the DD with lowest offset.

uint8_t const SVS = 1; //     "Remote" profiles are profiles that are assigned to buttons 1-12 on the RT4K remote. "SVS" profiles reside under the "/profile/SVS/" directory 
                      //     on the SD card.  This option allows you to choose which ones to call when a console is powered on.  Remote profiles allow you to easily change 
                      //     the profile being used for a console's switch input if your setup is in flux. SVS require you to rename the file itself on the SD card which is 
                      //     a little more work.  Regardless, SVS profiles will need to be used for console switch inputs over 12.
                      //
                      // **** Make sure "Auto Load SVS" is "On" under the RT4K Profiles menu. A requirement for most options ****
                      //
                      // 0 - use "Remote" profiles 1-12 for up to 12 inputs on 1st Extron Switch and SVS 13 - 99 for everything over 12. Only SVS profiles are used on 2nd Extron Switch if connected.
                      //
                      //     - remote profiles 1-12 for 1st Extron or TESmart Switch (If S0 below is set to true - remote profile 12 is used when all ports are in-active)
                      //     - SVS  12 - 99  for 1st Extron or TESmart (S0 is true)
                      //     - SVS  13 - 99  for 1st Extron or TESmart (S0 is false)
                      //     - SVS 101 - 199 for 2nd Extron or TESmart
                      //     - SVS 201 - 208 for 1st gScart
                      //     - SVS 209 - 216 for 2nd gScart
                      //
                      // 1 - use only "SVS" profiles.
                      //     Make sure "Auto Load SVS" is "On" under the RT4K Profiles menu
                      //     RT4K checks the /profile/SVS subfolder for profiles and need to be named: "S<input number>_<user defined>.rt4"
                      //     For example, SVS input 2 would look for a profile that is named S2_SNES.rt4
                      //     If there’s more than one profile that fits the pattern, the first match is used
                      //
                      //     - SVS   1 -  99 for 1st Extron or TESmart
                      //     - SVS 101 - 199 for 2nd Extron or TESmart
                      //     - SVS 201 - 208 for 1st gScart
                      //     - SVS 209 - 216 for 2nd gScart
                      //     - SVS   0       for S0 option mentioned below
                      //
                      //  ** If S0 below is set to true, create "/profile/SVS/S0_<user defined>.rt4" for when all ports are in-active. Ex: S0_HDMI.rt4
                      //
                      // 2 - use "Remote" profiles 1-12 for gscart/gcomp switches. Remote profile 1-8 for 1st gscart switch, 9-12 for inputs 1-4 on 2nd gscart switch.
                      //     inputs 5-8 on the 2nd gscart switch will use SVS profiles 213 - 216
                      //
                      //     - remote profiles 1-8 for 1st gScart, 9 - 12 for first 4 inputs on 2nd gScart (If S0 below is set to true - remote profile 12 is used when all ports are in-active)
                      //     - SVS 213 -  216 for remaining inputs 5 - 8 on 2nd gScart 
                      //     - SVS   1 -  99 for 1st Extron or TESmart
                      //     - SVS 101 - 199 for 2nd Extron or TESmart
                      //

bool const S0 = false;  // (Profile 0) default is false
                         //
                         //  ** Recommended to remove any /profile/SVS/S0_<user defined>.rt4 profiles and leave this option set false if using in tandem with the Scalable Video Switch. **
                         //  ** Does not work with TESmart HDMI switches **
                         //
                         // For SVS=0; set true to load "Remote Profile 12" when all ports are in-active on SW1 (and SW2 if connected). 
                         // You can assign it to a generic HDMI profile for example.
                         // If your device has a 12th input, SVS will be used instead. "If" you also have an active 2nd Extron Switch, Remote Profile 12
                         // will only load if "BOTH" switches have all in-active ports.
                         // 
                         // For SVS=1, /profile/SVS/ "S0_<user defined>.rt4" will load instead of Remote Profile 12
                         //
                         // For SVS=2, Remote Profile 12 will be used instead of "S0_<user defined>.rt4"
                         //

////////////////////////// 
                        // Choosing the above two options can get quite confusing (even for myself) so maybe this will help a little more:
                        //
                        // when S0=0 and SVS=0, button profiles 1 - 12 are used for EXTRON sw1, and SVS for EVERYTHING else
                        // when S0=0 and SVS=1, SVS profiles are used for everything
                        // when S0=0 and SVS=2, button profiles 1 - 8 are used for GSCART sw1, 9 - 12 for GSCART sw2 (ports 1 - 4), and SVS for EVERYTHING else
                        // when S0=1 and SVS=0, button profiles 1 - 11 are used for EXTRON sw1 and Remote Profile 12 as "Profile S0", and SVS for everything else 
                        // when S0=1 and SVS=1, SVS profiles for everything, and uses S0_<user defined>.rt4 as "Profile 0" 
                        // when S0=1 and SVS=2, button profiles 1 - 8 are used for GSCART sw1, 9 - 11 for GSCART sw2 (ports 1 - 3) and Remote Profile 12 as "Profile S0", and SVS for EVERYTHING else
                        //
//////////////////////////

// For Extron Matrix switches that support DSVP. RGBS and HDMI/DVI video types.

#define automatrixSW1 false // set true for auto matrix switching on "SW1" port
#define automatrixSW2 false // set true for auto matrix switching on "SW2" port

///////////////////////////////

uint8_t const ExtronVideoOutputPortSW1 = 1; // For certain Extron Matrix models, must specify the video output port that connects to RT4K
uint8_t const ExtronVideoOutputPortSW2 = 1; // can also be used for auto matrix mode as shown in next option

///////////////////////////////

uint8_t const vinMatrix[65] = {0,  // MATRIX switchers  // When auto matrix mode is enabled: (automatrixSW1 / SW2 defined above)
                                                        // set to 0 for the auto switched input to tie to all outputs
                                                        // set to 1 for the auto switched input to trigger a Preset
                                                        // set to 2 for the auto switched input to tie to "ExtronVideoOutputPortSW1" / "ExtronVideoOutputPortSW2"
                                                        //
                                                        // For option 1, set the following inputs to the desired Preset #
                                                        // (by default each input # is set to the same corresponding Preset #)
                           1,  // input 1 SW1
                           2,  // input 2
                           3,  // input 3
                           4,  // input 4
                           5,  // input 5
                           6,  // input 6
                           7,  // input 7
                           8,  // input 8
                           9,  // input 9
                           10,  // input 10
                           11,  // input 11
                           12,  // input 12
                           13,  // input 13
                           14,  // input 14
                           15,  // input 15
                           16,  // input 16
                           17,  // input 17
                           18,  // input 18
                           19,  // input 19
                           20,  // input 20
                           21,  // input 21
                           22,  // input 22
                           23,  // input 23
                           24,  // input 24
                           25,  // input 25
                           26,  // input 26
                           27,  // input 27
                           28,  // input 28
                           29,  // input 29
                           30,  // input 30
                           30,  // input 31
                           30,  // input 32
                               //
                               // ONLY USE FOR 2ND MATRIX SWITCH on SW2
                           1,  // 2ND MATRIX SWITCH input 1 SW2
                           2,  // 2ND MATRIX SWITCH input 2
                           3,  // 2ND MATRIX SWITCH input 3
                           4,  // 2ND MATRIX SWITCH input 4
                           5,  // 2ND MATRIX SWITCH input 5
                           6,  // 2ND MATRIX SWITCH input 6
                           7,  // 2ND MATRIX SWITCH input 7
                           8,  // 2ND MATRIX SWITCH input 8
                           9,  // 2ND MATRIX SWITCH input 9
                           10,  // 2ND MATRIX SWITCH input 10
                           11,  // 2ND MATRIX SWITCH input 11
                           12,  // 2ND MATRIX SWITCH input 12
                           13,  // 2ND MATRIX SWITCH input 13
                           14,  // 2ND MATRIX SWITCH input 14
                           15,  // 2ND MATRIX SWITCH input 15
                           16,  // 2ND MATRIX SWITCH input 16
                           17,  // 2ND MATRIX SWITCH input 17
                           18,  // 2ND MATRIX SWITCH input 18
                           19,  // 2ND MATRIX SWITCH input 19
                           20,  // 2ND MATRIX SWITCH input 20
                           21,  // 2ND MATRIX SWITCH input 21
                           22,  // 2ND MATRIX SWITCH input 22
                           23,  // 2ND MATRIX SWITCH input 23
                           24,  // 2ND MATRIX SWITCH input 24
                           25,  // 2ND MATRIX SWITCH input 25
                           26,  // 2ND MATRIX SWITCH input 26
                           27,  // 2ND MATRIX SWITCH input 27
                           28,  // 2ND MATRIX SWITCH input 28
                           29,  // 2ND MATRIX SWITCH input 29
                           30,  // 2ND MATRIX SWITCH input 30
                           30,  // 2ND MATRIX SWITCH input 31
                           30,  // 2ND MATRIX SWITCH input 32
                           };

                           // ** Must be on firmware version 3.7 or higher **
uint8_t const RT5Xir = 0;     // 0 = disables IR Emitter for RetroTink 5x
                              // 1 = enabled for Extron sw1 / alt sw1, TESmart HDMI, MT-ViKi, or Otaku Games Scart Switch if connected
                              //     sends Profile 1 - 10 commands to RetroTink 5x. Must have IR LED emitter connected.
                              //
                              // 2 = enabled for gscart switch only (remote profiles 1-8 for first gscart, 9-10 for first 2 inputs on second gscart)
                              //
                              // 3 = enabled for Extron sw2 / alt sw2, TESmart HDMI, MT-ViKi, or Otaku Games Scart Switch if connected 
                              //     sends Profile 1 - 10 commands to RetroTink 5x. Must have IR LED emitter connected.

uint8_t const OSSCir = 0;     // 0 = disables IR Emitter for OSSC
                              // 1 = enabled for Extron sw1 switch, TESmart HDMI, or Otaku Games Scart Switch if connected
                              //     sends Profile 1 - 14 commands to OSSC. Must have IR LED emitter connected.
                              //     
                              // 2 = enabled for gscart switch only (remote profiles 1-8 for first gscart, 9-14 for first 6 inputs on second gscart)

uint8_t const MTVir = 0;   // Must have IR "Receiver" connected to the Donut Dongle for option 1 & 2.
                              // 0 = disables IR Receiver -> Serial Control for MT-VIKI 8 Port HDMI switch
                              //
                              // 1 = MT-VIKI 8 Port HDMI switch connected to "Extron sw1"
                              //     Using the RT4K Remote w/ the IR Receiver, AUX8 + profile button changes the MT-VIKI Input over Serial.
                              //     Sends auxprof SVS profiles listed below.
                              //
                              // 2 = MT-VIKI 8 Port HDMI switch connected to "Extron sw2"
                              //     Using the RT4K Remote w/ the IR Receiver, AUX8 + profile button changes the MT-VIKI Input over Serial.
                              //     Sends auxprof SVS profiles listed below. You can change them below to 101 - 108 to prevent SVS profile conflicts if needed.
                              // 3 = MT-VIKI 8 Port HDMI switch connected to BOTH "alt sw1" and "alt sw2"
                              //     Use AUX7 and AUX8 buttons as described above.
                              //

uint8_t const TESmartir = 0;  // Must have IR "Receiver" connected to the Donut Dongle for option 1 and above.
                              // 0 = disables IR Receiver -> Serial Control for TESmart 16x1 Port HDMI switch
                              //
                              // 1 = TESmart 16x1 HDMI switch connected to "alt sw1"
                              //     Using the RT4K Remote w/ the IR Receiver, AUX7 + profile button changes the Input over Serial. AUX7 + AUX1 - AUX4 for Input 13 - 16.
                              //     Sends SVS profile 1 - 16 as well.
                              //
                              // 2 = TESmart 16x1 HDMI switch connected to "alt sw2"
                              //     Using the RT4K Remote w/ the IR Receiver, AUX8 + profile button changes the Input over Serial. AUX8 + AUX1 - AUX4 for Input 13 - 16.
                              //     Sends SVS profile 101 - 116 as well.
                              //
                              // 3 = TESmart 16x1 HDMI switch connected to BOTH "alt sw1" and "alt sw2"
                              //     Use AUX7 and AUX8 buttons as described above.
                              //

uint8_t const auxprof[12] =   // Assign SVS profiles to IR remote profile buttons. 
                              // Replace 1, 2, 3, etc below with "ANY" SVS profile number.
                              // Press SAFE button then profile button to load. Must have IR Receiver connected and Serial connection to RT4K.
                              //
                              // 
                              {1,  // SAFE + profile 1 button
                                2,  // SAFE + profile 2 button
                                3,  // SAFE + profile 3 button
                                4,  // SAFE + profile 4 button
                                5,  // SAFE + profile 5 button
                                6,  // SAFE + profile 6 button
                                7,  // SAFE + profile 7 button
                                8,  // SAFE + profile 8 button
                                9,  // SAFE + profile 9 button
                                10, // SAFE + profile 10 button
                                11, // SAFE + profile 11 button
                                12, // SAFE + profile 12 button
                                };

uint8_t const gctl = 0; // 1 = Enables gscart/gcomp manual input selection
                        // 0 = Disable (Default)
                        //
                        // ** Only supported on vers 5.x gscart/gcomp switches **
                        //
                        // AUX5 button + 1-8 button for gscart sw1, button 1 = input 1, etc
                        // AUX5 + 9-12 button to return to auto switching
                        //
                        // AUX6 button + 1-8 button for gscart sw2, button 1 = input 1, etc
                        // AUX6 + 9-12 button to return to auto switching
                        // 
                        // (RT5x and OSSC may require a repeat of the button combo for the IR signal to send.)

char const auxpower[] = "LG"; // AUX8 + Power button sends power off/on via IR Emitter. "LG" OLEX CX is the only one implemented atm.
```

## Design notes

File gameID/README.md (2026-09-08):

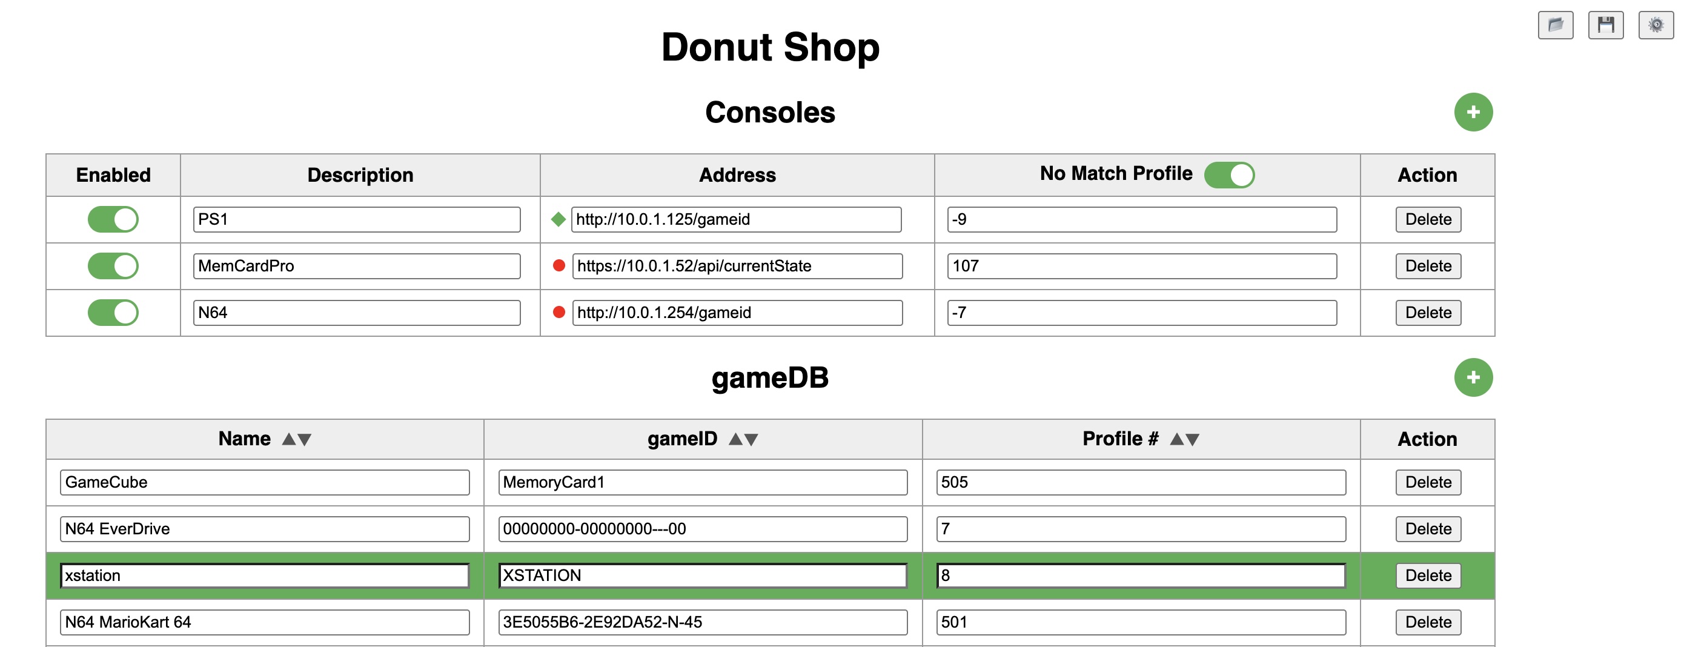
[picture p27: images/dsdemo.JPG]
<br />
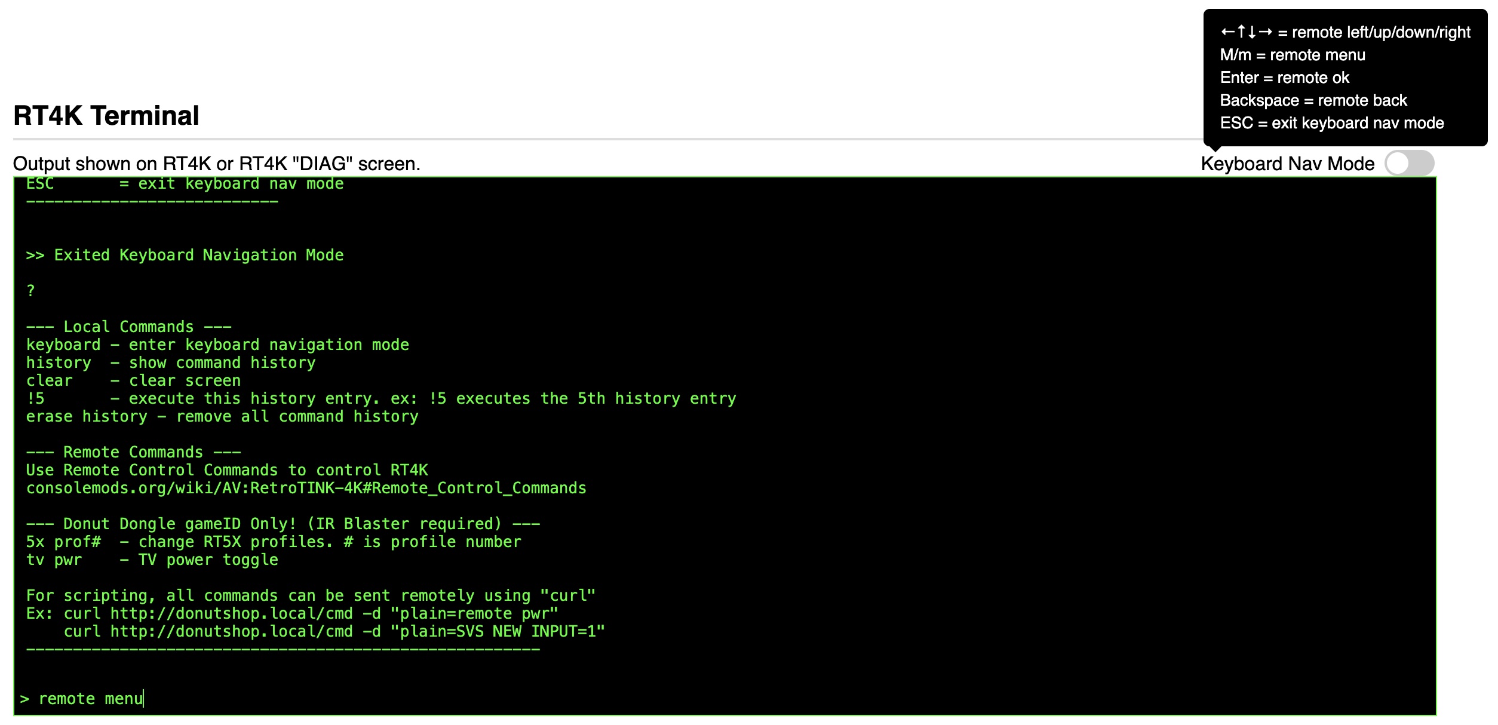
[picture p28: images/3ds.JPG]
<br />

## gameID devices currently supported
| **Device** | Supported | Notes |
| --- | --- |--- |
|PS1Digital | yes, confirmed first hand | |
|N64Digital | yes, confirmed first hand | |
|RetroGEM N64 | yes | |
|RetroGEM PS1 | yes | |
| MemCardPro 2 | yes, for GameCube, PS1, & PS2 | MemCardPro 2.0+ firmware requires https instead of http |
| Fenrir ?| | |
| more on the way... |  

### LED activity
| **Color** | Blinking | On | Notes |
| --- | --- |--- |--- |
| 🟠| | Wifi not connected | After 2 minutes of unsuccessfully connecting, "DonutShop_Setup" Wifi AP will reappear to help with reconnection. |
| 🔵| WiFi active, querying gameID addresses| Longer blinks represent an unsuccessful query of gameID address. Usually a powered off console in the list.| After initial power, no BLUE light means WiFi not found. |
| 🟢| 1 second blink is gameID match found and SVS profile being sent to RT4K | |  | 
| 🔴| | Power| No way to control as it's hardwired in. May just need to cover with tape. |

## Flashing 
1. Open the [Donut Dongle gameID Firmware Installer](https://svirant.github.io/DonutDongle/install/) in Brave/Chrome/Edge.
2. Once complete, reconnect the USB cable of the device and continue **Setup** below...
3. If you get an error, try the Alternative Flashing steps at the bottom of the page.

## Setup
1. Upon reconnecting the USB cable, your board should **Successfully boot DonutShop** and leave you with an ORANGE led.
2. With your computer or smartphone, join the broadcasted ```DonutShop_Setup``` WiFi to connect it to your home network.
    - You can now also change the default "donutshop" Hostname. Must follow the rules listed and will have .local appended automatically.
    - ONLY "a-z", "0-9", and "-" (hyphen) characters are allowed. (edge hyphens not allowed)
3. Follow the instructions listed and once complete, you should see a BLUE led indicating it's connected to WiFi and looking for addresses to connect to. If the BLUE led does not show, press the RST button one time.
4. You should now be able to visit http://donutshop.local to confirm WiFi connectivity.
5. Disconnect the Arduino Nano ESP32 and connect it to the OTG adapter. Connect the OTG assembly to the RT4K and everything should power on.
6. Reconfirm connectivity to http://donutshop.local and refresh the page after the RT4K has fully booted.
7. For all updates you can visit the "Firmware Update" section in Settings to "Check for Updates" and auto update to the latest.
8. There is also a manual update section where you can apply any version's _update .bin file. Updating manually with the _full version will not work.
   
## General Setup

For Consoles, quickest if IP address is used versus Domain address:
  - Ex: http://10.0.1.10/gameid vs http://ps1digital.local/gameid 

If you have multiple consoles on when DonutShop is booting, the console furthest down the list wins. If more than 2 consoles are active when one is powered off, the console that was on prior takes over. (Order is remembered.)<br>

## Adding gameIDs, Consoles, and other Options

The Web UI allows you to live update the Consoles and gameID table. You no longer have to reflash for changes. You can also now import and export your config if anything were to happen and you need to rebuild.

## WiFi setup
**ONLY** compatible with **2.4GHz** WiFi APs. Configured during initial setup process. If you need to change SSID or password, the "DonutShop_Setup" AP will reappear after 2 minutes of not being able to connect.

## New IR Remote Control functionality
When using the optional IR Receiver, the IR reception of the RT4K can be been greatly enhanced. You can think of it as an IR repeater, but instead talks to the RT4K via Serial for solid communication. Since the Donut Dongle is in the middle, other remote features can be added such as:
 - **Alternate SVS Profiles**: Have you ever wanted to add CRT effects to all of your existing SVS profiles? Or wanted all your profiles to output at 1080p instead of 4K? With this feature you can create a set of SVS profiles that have these changes and activate the system with the remote. Pressing the "SAFE" button twice + 1 - 9 buttons will allow you to configure 9 different sets of these profiles per regular profile to load instead of the regular one you created. For example: Instead of SVS profile S1_SNES.rt4 loading, S1001_SNES.rt4 will load instead after activating with the "SAFE"x2 + 1 button. Here are some more examples so you can see the pattern used for creating these: </br>

    "SAFE"x2 + x button = Sx001_SNES-CRT.rt4, where x is the number button selected and 001 is the S1_ profile represented in 3 digits. </br>
    "SAFE"x2 + 2 button = S2001_SNES-1080p.rt4 </br>
    "SAFE"x2 + 3 button = S3001_SNES-Zoomed.rt4 </br>
    "SAFE"x2 + 4 button = S4001_SNES.rt4 </br>
    "SAFE"x2 + 5 button = S5001_SNES.rt4 </br>
    "SAFE"x2 + 6 button = S6001_SNES.rt4 </br>
    "SAFE"x2 + 7 button = S7001_SNES.rt4 </br>
    "SAFE"x2 + 8 button = S8001_SNES.rt4 </br>
    "SAFE"x2 + 9 button = S9001_SNES.rt4 </br> 

   - The name following the "\_" can be changed as well. So a name like S1001_SNES-CRT.rt4 can be used to better describe. Only the naming pattern before the "\_" is important. </br>

   - When SVS profile S2 normally would load, Sx002 would load instead where x = the number button chosen prior and 002 represents the S2 profile. S2100_NES.rt4 for example would be the 2nd Alternate profile for S100_NES.rt4. It's up to you to create these alternate sets of profiles on your SD card of course. To disable this feature and return to your normally configured profiles, press "SAFE"x2  + 10, 11, or 12 buttons on the remote.

 - SAFE button once + profile button 1 - 12 loads SVS profiles of your choosing. By default is SVS 1 - 12. Configured with auxprof[] in the Settings section of the .ino
  
 - Normally, if you power on your console before waking the RT4K, the RT4K will have not seen the profile change. Using the remote's POWER button, in this configuration, will wake the RT4K "and" resend the profile after it's finished waking.

 - AUX8 button + Power button power cycles your TV via IR Emitter. (only LG OLED CX atm, more can be added upon request)

 - AUX8 pressed twice, manually enter a SVS profile to load with the profile buttons using 1 - 9 and 10,11,12 buttons for 0. Must use 3 digits. Ex: 001 = 1, 010 = 10, etc

 - AUX8 pressed 3x will perform the standard AUX8 action

 - AUX5 will load the previous profile. Repeated presses will switch back/forth the last 2 profiles. Great for A/B comparisons.
 
 - MT-ViKI 8 Port HDMI switch's inputs can be changed. Must configure "MTVir" in the options section of the .ino
    - AUX7 + button 1 - 8 for inputs 1 - 8 on "alt sw1" port (SVS profiles 1 - 8)
    - AUX8 + button 1 - 8 for inputs 1 - 8 on "alt sw2" port (SVS profiles 101 - 108)

 - TESmart 16x1 HDMI switch's inputs can changed. Must set "TESmartir" in the options section.
    - AUX7 + button 1 - 12, aux1, aux2, aux3, aux4 for inputs 1 - 16 on "alt sw1" port (SVS profiles 1 - 16)
    - AUX8 + button 1 - 12, aux1,aux2,aux3,aux4 for inputs 1 - 16 on "alt sw2" port (SVS profiles 101 - 116)

## [Advanced] Programming the Arduino Nano ESP32 with custom .ino changes
I recommend the [Official Arduino IDE and guide](https://docs.arduino.cc/software/ide-v2/tutorials/getting-started-ide-v2/) if you're unfamiliar with Arduinos. All .ino files used for programming are listed above. The following Libraries will also need to be added in order to Compile successfully.<br />
- **Add Additional Boards**
  - In the Arduino IDE open up "Settings", find the section "Additional boards manager URLs:"
  - Add in: https://espressif.github.io/arduino-esp32/package_esp32_index.json and select "OK"
1. First, you must have completed the steps shown in the "Flashing" section above at least once before continuing.
2. "Double click" the RST button right after connecting to your PC/Mac to put into "recovery mode". You'll see a GREEN led strobe if successful.
3. Open up Donut_Dongle_gameID.ino in the Arduino IDE to make your custom changes.
4. Under the "Tools" menu, make sure...
- Board - "esp32" -> "Arduino Nano ESP32" is selected. DO NOT select "Arduino ESP32 Boards" -> "Arduino Nano ESP32"
- Port - The listed "Serial" port is chosen, not dfu one.
    - If Donut_Shop is currently running, you should also see a "DonutShop" Network Port that connects via WiFi.
- Core Debug Level - "None"
- Partition Scheme - "With SPIFFS partition (advanced)" is chosen
- Pin Numbering - "By Arduino pin (default)"
- USB Mode - "Debug mode (Hardware CDC)" / **Important that this is selected!**
5. To flash the changes, select "Sketch" -> "Upload"

## Alternative Flashing Steps
1. Open [ESP Tool](https://espressif.github.io/esptool-js/) in Chrome, Brave, or Edge
2. Connect your Arduino Nano ESP32 via USB directly to your PC or Mac (not through a usb-hub) and double click the Nano's RST button immediately following to enter **recovery mode** (a GREEN led will strobe when successful)
3. Clicking **Connect** opens up a selection menu and you should see something like (depending on OS and Nano brand) Nano ESP32 or TinyUSB
4. With the **Connect menu** still open, single click the Nano button once more and quickly select the new device named USB JTAG; click **Connect**
    - If it disappears, click the Nano button again for it to return. Be faster this time! ;)
    - If you get errors going forward, try changing to a lower Baudrate
5. Click **Erase Flash** to format your device (required for LittleFS)
6. Download the latest files from the Github Releases section.
7. Set Flash Address to **0x0** and Choose the file ```Donut_Dongle_gameID_vX.X.X_full.bin```
8. Click **Add File**, set the next Flash Address to **0xF70000**, Choose ```nora_recovery.bin```
9. Click **Program**
10. Once complete, reconnect the USB cable of the device and continue **Setup** below...

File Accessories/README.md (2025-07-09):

# Accessories:
 - Gerbers (.zip) files needed for PCB manufacturing listed above.
    - 1.0mm PCB Thickness preferred for gscart_ext_conenctor
    - 1.6mm for all others
    - For Surface Finish, "HASL(with lead)" is fine
    - Option to "Remove Mark" is free now on JLCPCB
    - All remaining default options should be fine
    - Let me know if you have any questions!
 - gscart/gcomp EXT, TESmart HDMI, and alt Extron connectors are showcased in the main README

 ### MT-VIKI / Extron / DB9 to 3.5mm adapter
  - .3mf for 3DP housing listed above
  - BOM listed on Main README
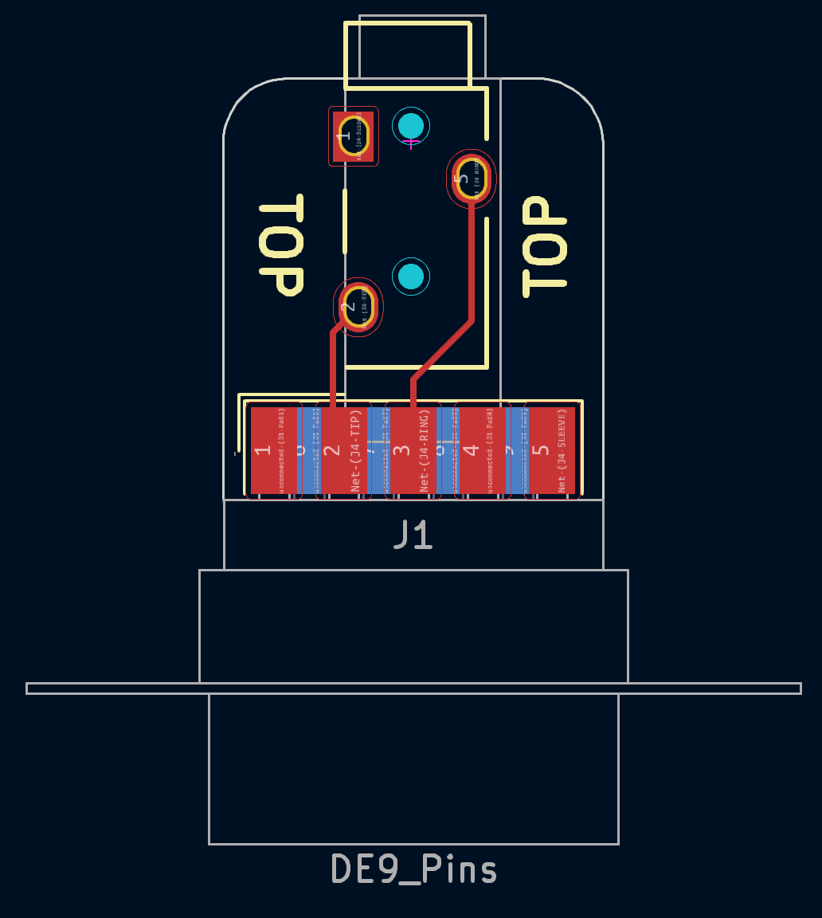
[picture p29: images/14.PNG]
 

 ### TESmart_connector
  - BOM listed on Main README
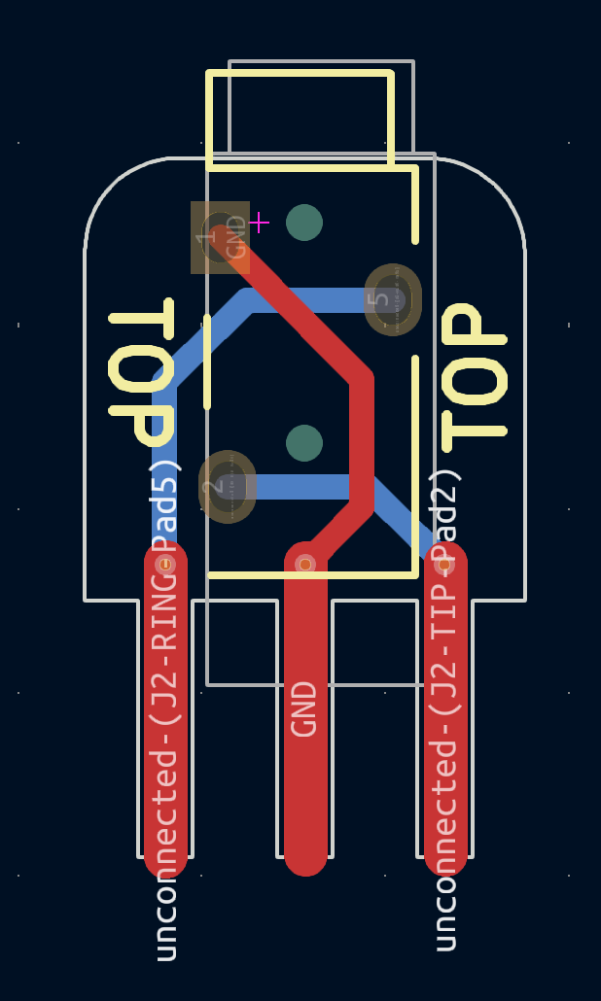
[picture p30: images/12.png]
 

 ### gscart_ext_connector (gcomp too!)
  - BOM listed on Main README
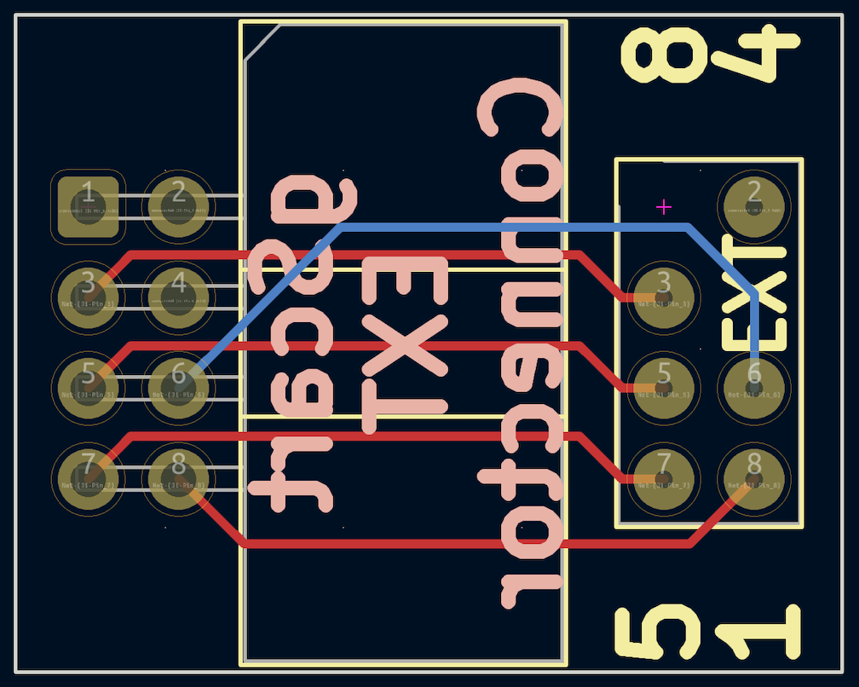
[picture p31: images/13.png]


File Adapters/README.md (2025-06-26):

# VGA Adapters for use with the Donut Dongle:
Gerbers (.zip) files needed for PCB manufacturing listed above.
 - 1.6mm PCB Thickness
 - For Surface Finish, "HASL(with lead)" is fine
 - Option to "Remove Mark" is free now on JLCPCB
 - All remaining default options should be fine
 - Let me know if you have any questions!

## 3D printed VGA Passthrough case
 - Courtesy of "HerraAAV3" from the RetroTink discord. Thank you so much for contributing to the project!
 - .3MF files listed above 

### VGAPassthrough_wSharedSerial "shared serial bus"
 - Passes all video AND non-video signals (Pins 12,15) which allow it to cohabitate with the [Scalable Video Switch](https://scalablevideoswitch.com)
 - 4 Layer design
 - Option to disconnect non-video signals (SDA/SCL) of VGA source. (Only if interfering with Serial operations)
 - Designed for use with #4-40 x 3/4" jackscrew "bolts" for heavier VGA cable support.
 - BOM listed on Main README

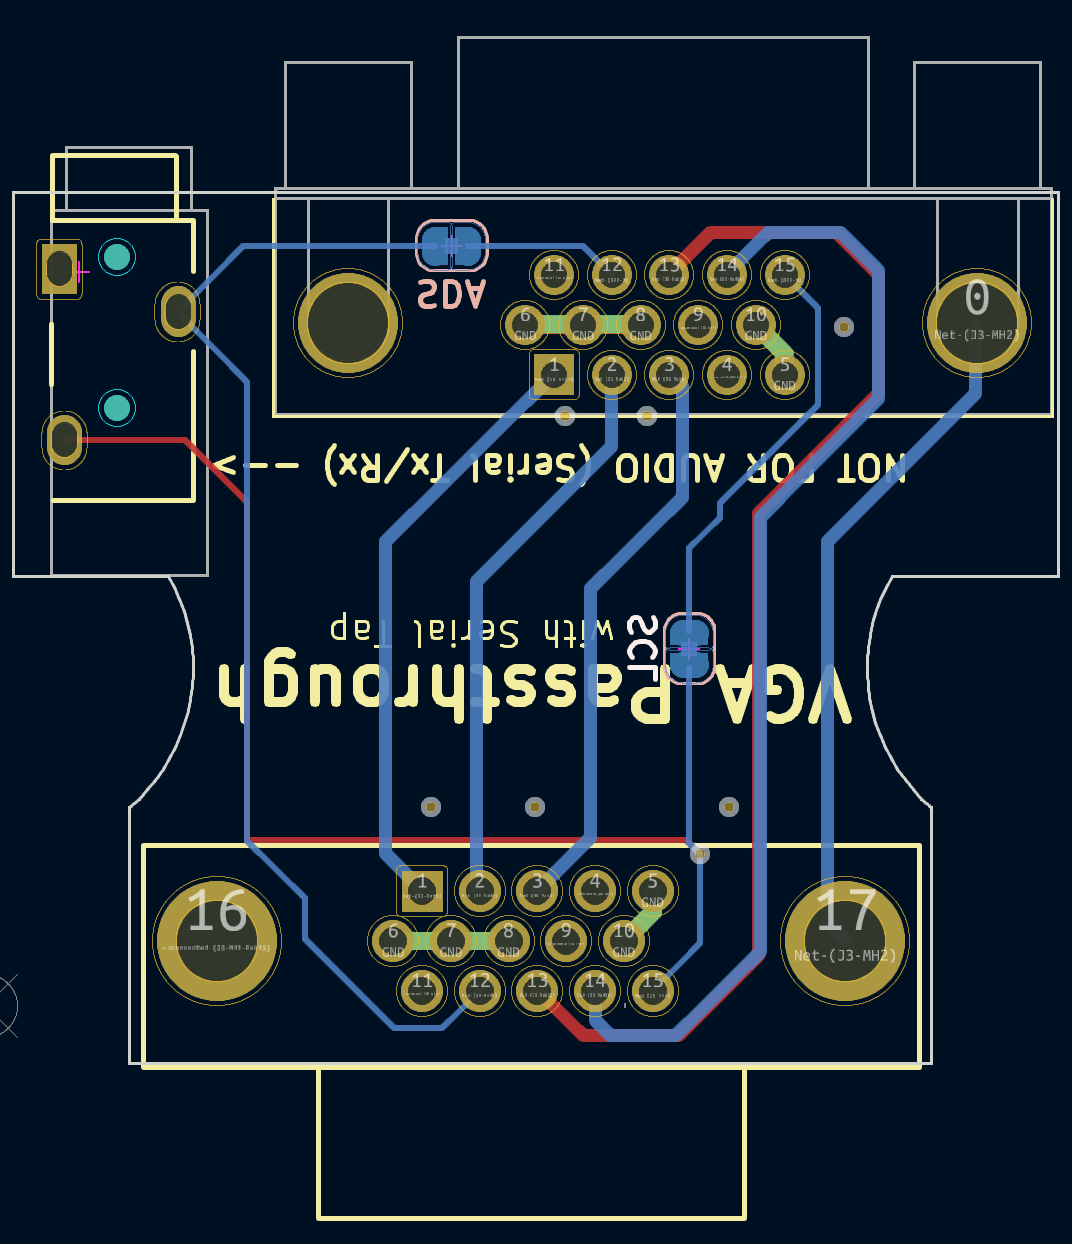
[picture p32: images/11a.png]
 <br />


<br />

### YC2VGA_wSerial (new/smaller version)
 - 4 Layer design
 - Adds the bonus of converting the VGA port into Enhanced S-video and Composite inputs.
 - Pushon connector is nice and snug, no need for jackscrews.
 - BOM listed on Main README

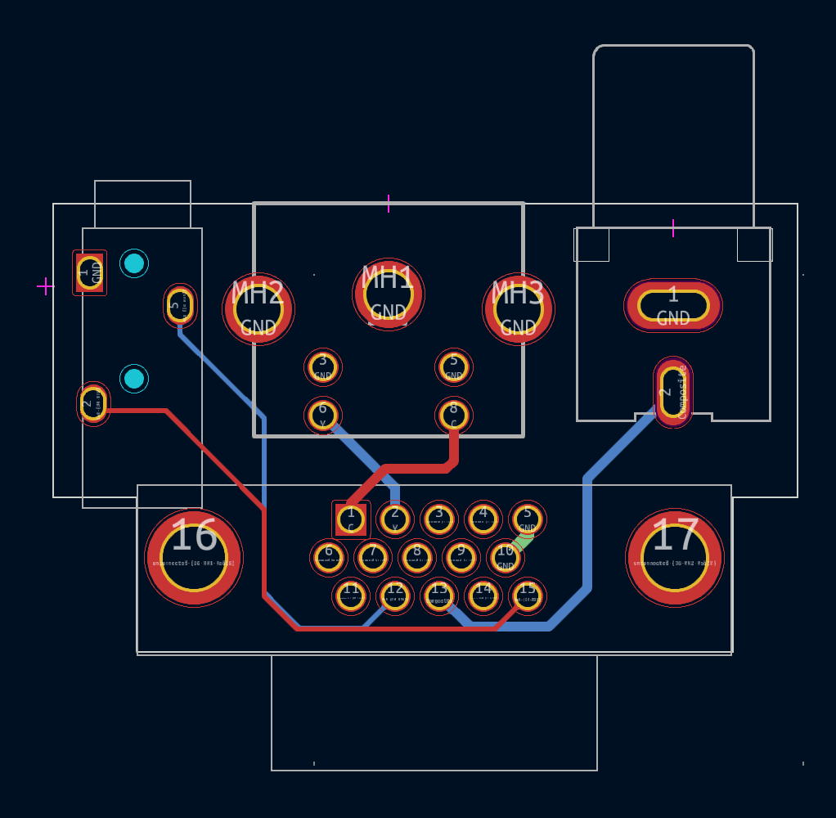
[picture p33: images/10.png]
 <br />


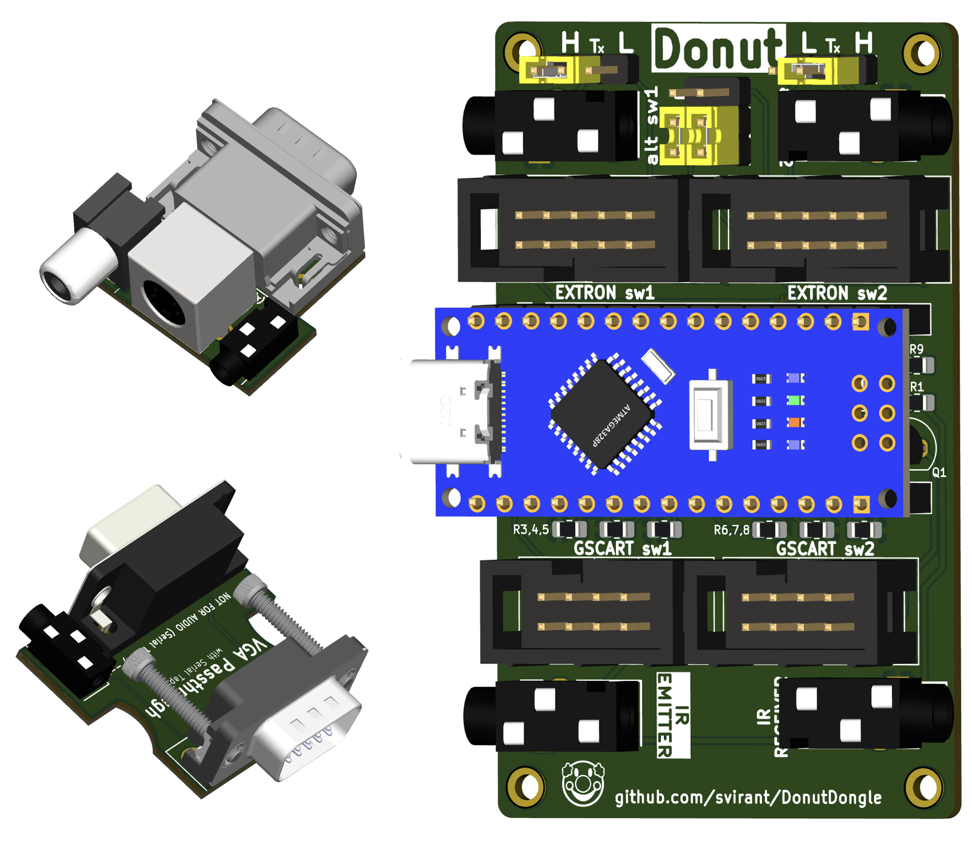
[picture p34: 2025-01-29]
images/1a.png

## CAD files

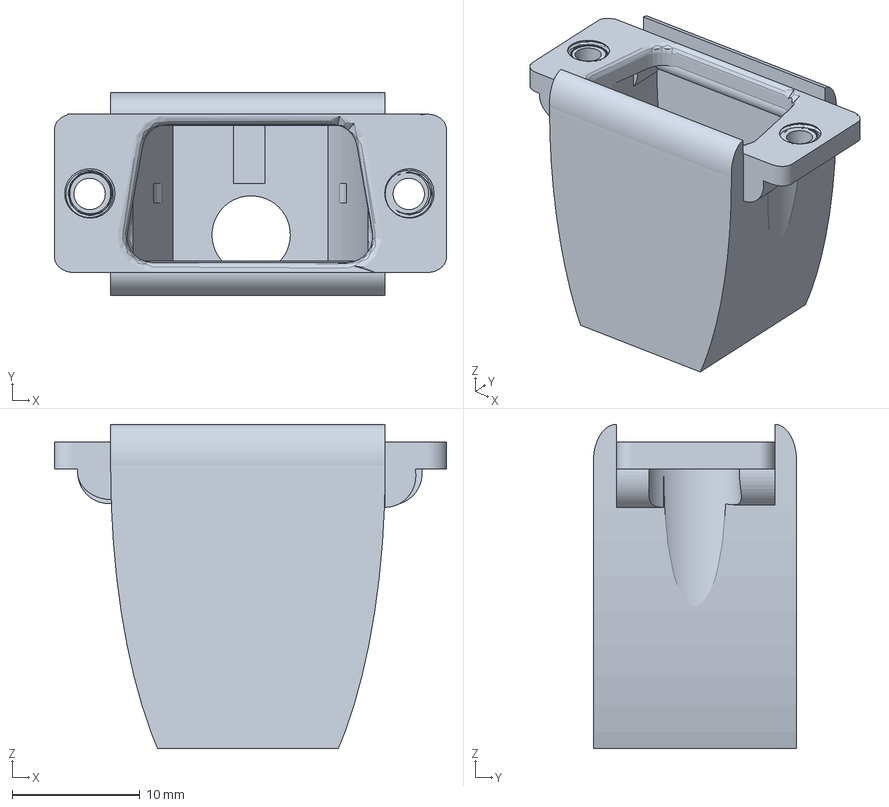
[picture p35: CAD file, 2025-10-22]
Accessories/DB9-35mm.3mf
30.7 x 15.9 x 25.4 mm

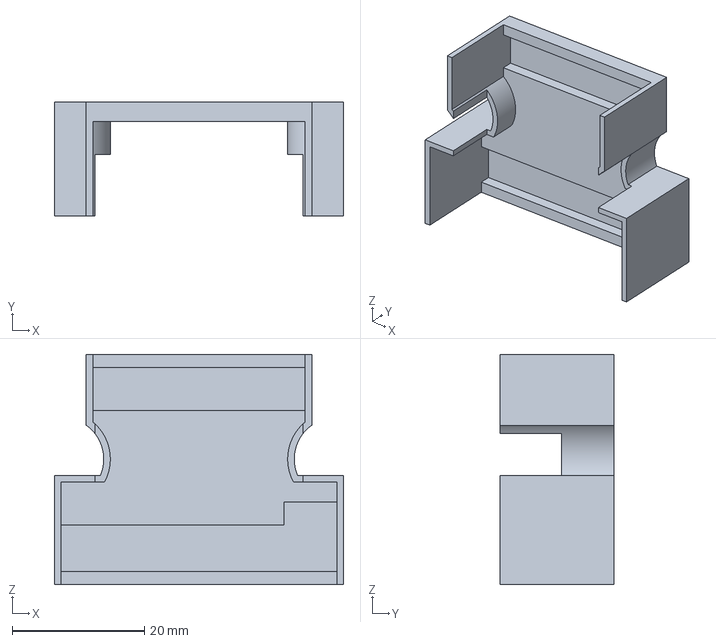
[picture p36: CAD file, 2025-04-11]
Adapters/VGAPassthrough bottom.3MF
43.7 x 17.3 x 34.8 mm

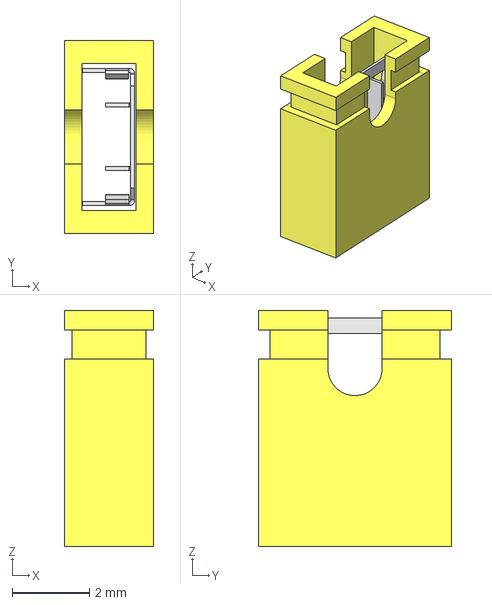
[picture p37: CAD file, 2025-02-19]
src/3D/Jumper.step
2.30 x 5.00 x 6.10 mm
Frame
Jump

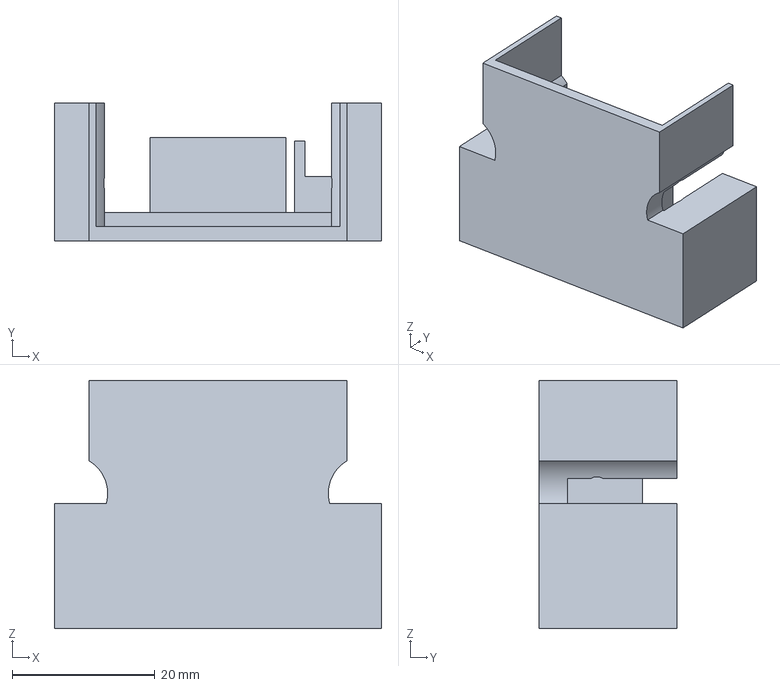
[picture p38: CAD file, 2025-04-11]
Adapters/VGAPassthrough top.3MF
45.8 x 19.3 x 34.8 mm

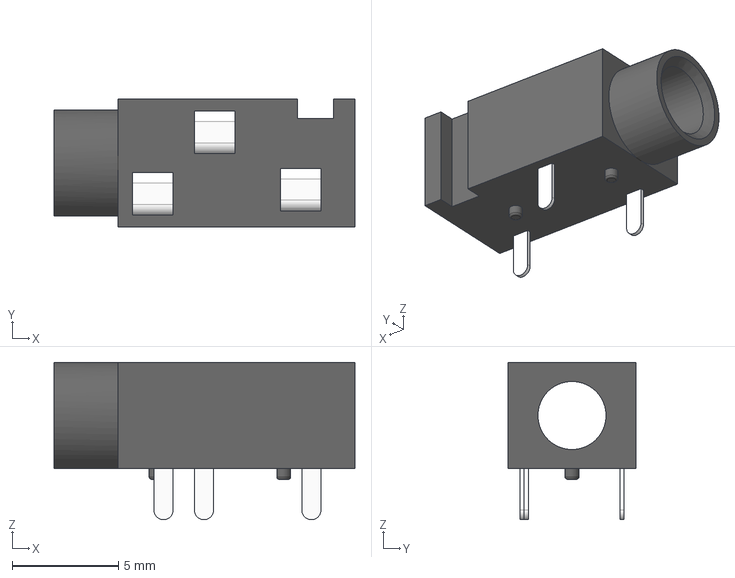
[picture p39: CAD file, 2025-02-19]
src/3D/PJ-320.stp
14.2 x 6.00 x 7.40 mm

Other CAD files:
Accessories/DB9-35mm.stl

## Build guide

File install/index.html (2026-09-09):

WebUSB and Web Serial are required. Use Chrome or Edge on desktop.

## Donut Dongle gameID Firmware Installer

— • —

Arduino / Waveshare Nano ESP32 compatible.

Release Notes

1. Windows 10/11 first-time setup: Install Arduino’s official Nano ESP32 USB driver before continuing. Arduino ESP32 drivers-only package (6MB) (https://svirant.github.io/DonutDongle/install/Arduino-Nano-ESP32_drivers.zip). Extract the ZIP, open the drivers folder, then run dpinst-amd64.exe on 64-bit Windows 10 or any Windows 11 PC. Use dpinst-x86.exe only for 32-bit Windows 10. This is only required once.
2. Connect your Nano ESP32 via USB directly to your PC or Mac (not through a USB hub) and double click the Nano's RST button to enter recovery mode (a GREEN LED will strobe when successful).
3. Click “Connect and Flash” and select “ARDUINO_NANO_NORA” (or “Nano ESP32 (bootloader)”). When “Authorize USB JTAG” appears, follow the instruction shown below the button.
4. After installation, continue with the “Setup” steps listed on GitHub.

Connect and Flash Authorize USB JTAG

Click “Authorize USB JTAG”, leave the chooser open, press RST on the Nano once, then select the USB JTAG device when it appears.

Donut Dongle gameID installed successfully.

Log

0% 0%

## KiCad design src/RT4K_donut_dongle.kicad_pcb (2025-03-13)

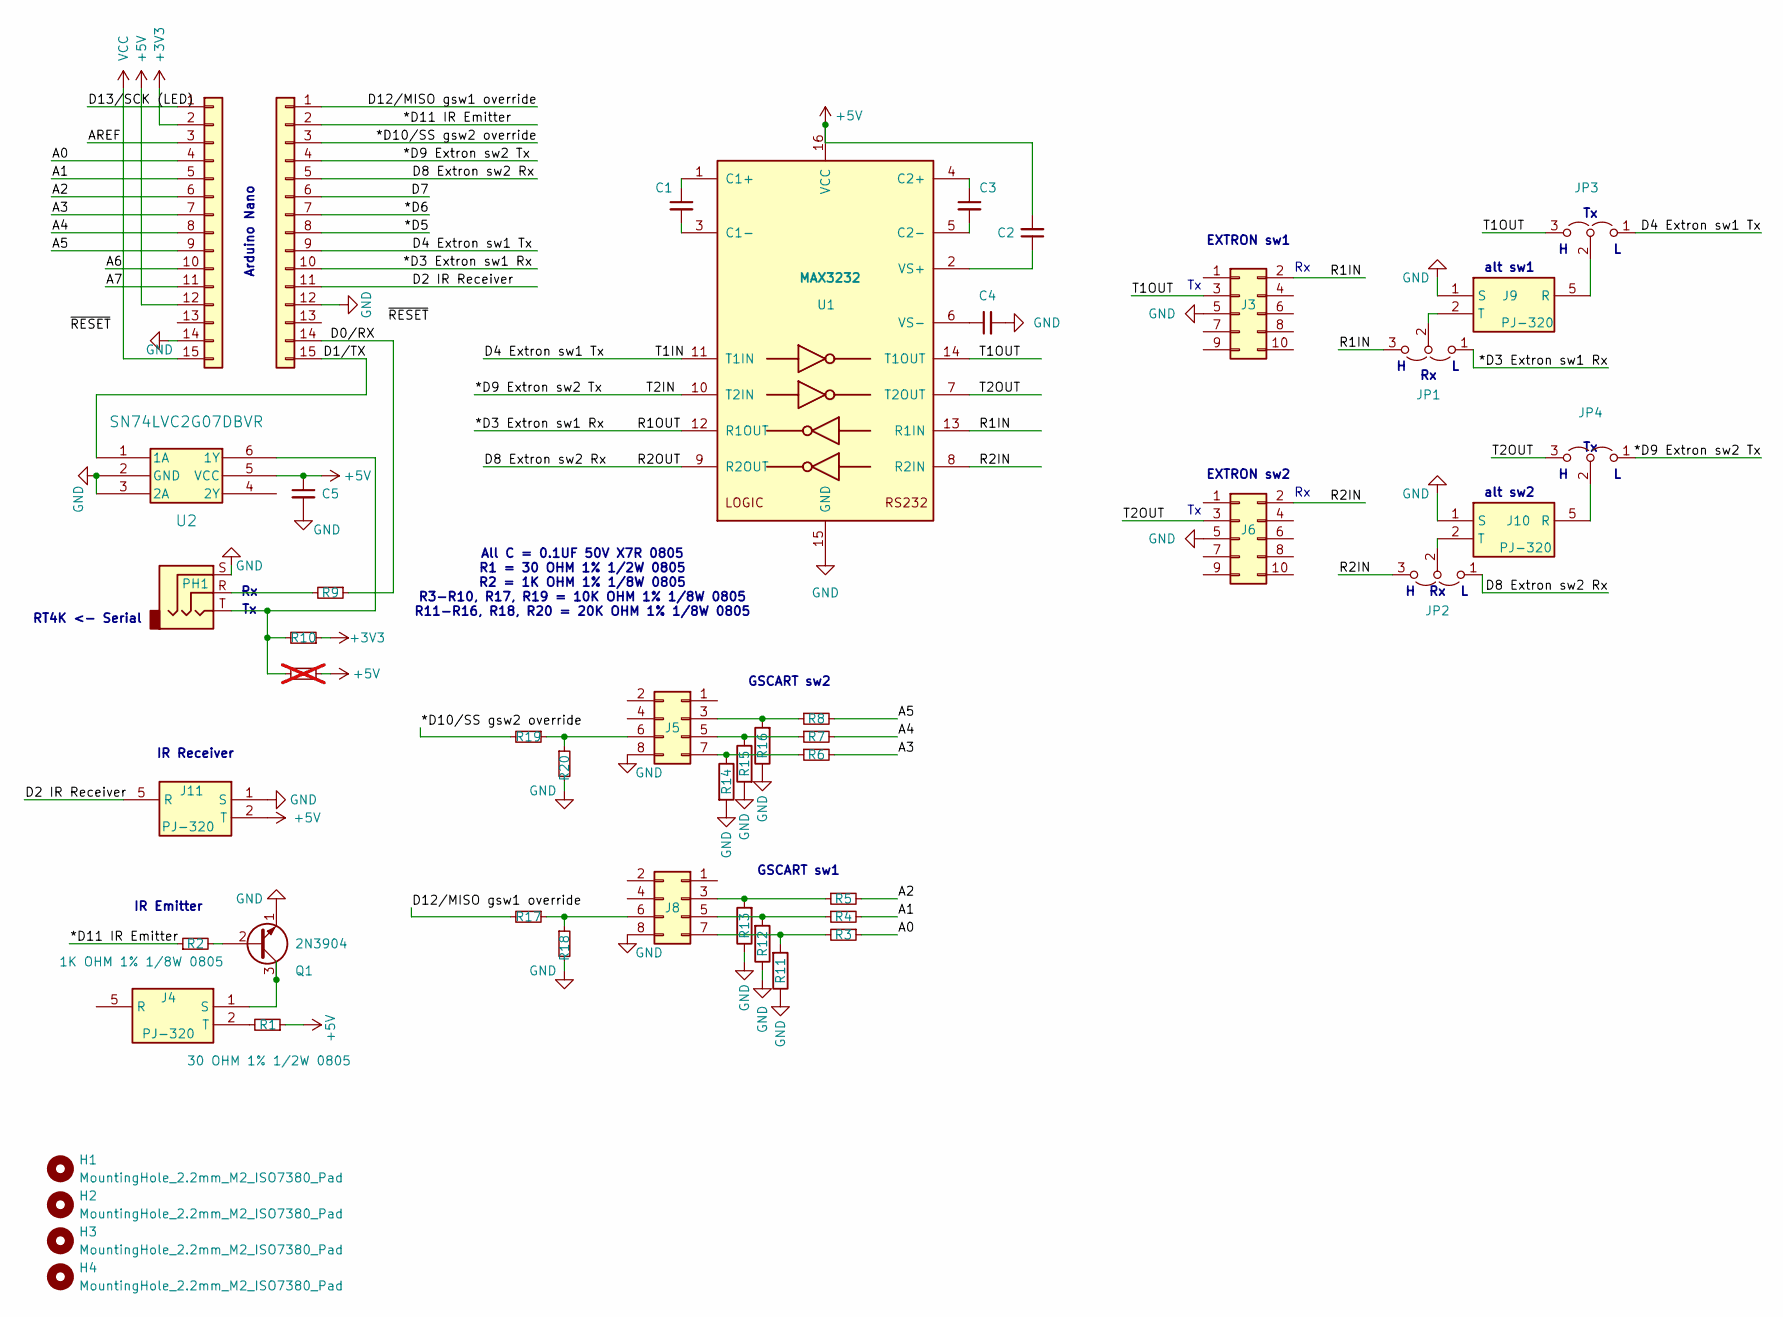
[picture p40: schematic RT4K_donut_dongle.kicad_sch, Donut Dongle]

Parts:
C1, C2, C3, C4, C5: 0.1UF 50V X7R 0805; C_0805_2012Metric_Pad1.18x1.45mm_HandSolder
H1, H2, H3, H4: MountingHole_2.2mm_M2_ISO7380_Pad
J1, J2: 2.54mm Pitch Single Row Female 15P Header Strip; PinSocket_1x15_P2.54mm_Vertical
J3, J6: 2x5 Pin Double Row 2.54mm Pitch Straight Box Head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; IDC-Header_2x05_P2.54mm_Vertical
J4, J9, J10, J11: PJ-320; SJ335083ATR; Mouser Part Number 179-SJ3-35083A-TR
J5, J8: 2x4 Pin Double Row 2.54mm Pitch Straight Box Head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; IDC-Header_2x04_P2.54mm_Vertical
JP1, JP2: Jumper_3_Open; PinHeader_1x03_P2.54mm_Vertical
JP3, JP4: PinHeader_1x03_P2.54mm_Vertical
PH1: PJ-307; Jack_3.5mm_CUI_SJ1-3525N_Horizontal
Q1: 2N3904; TO-92_Inline
R1: 30 OHM 1% 1/2W 0805; R_0805_2012Metric_Pad1.20x1.40mm_HandSolder
R2: 1K OHM 1% 1/8W 0805; R_0805_2012Metric_Pad1.20x1.40mm_HandSolder
R3, R4, R5, R6, R7, R8, R9, R10, R17, R19: 10K OHM 1% 1/8W 0805; R_0805_2012Metric_Pad1.20x1.40mm_HandSolder
R11, R12, R13, R14, R15, R16, R18, R20: 20K OHM 1% 1/8W 0805; R_0805_2012Metric_Pad1.20x1.40mm_HandSolder
R21: 10K OHM 1% 1/8W 0805; R_0805_2012Metric_Pad1.20x1.40mm_HandSolder; not fitted
U1: MAX3232; SOIC-16W_5.3x10.2mm_P1.27mm
U2: SN74LVC2G07DBVR; TSOT-23-6_HandSoldering

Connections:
+3V3: J1.2, R10.1
+5V: C2.2, C5.1, J1.12, J11.2 (T), R1.1, R21.1, U1.16 (VCC), U2.5 (VCC)
/*D3 Extron sw1 Rx: J2.10, JP1.1 (A), U1.12 (R1OUT); also elsewhere on the board
/*D9 Extron sw2 Tx: J2.4, JP4.1 (A), U1.10 (T2IN); also elsewhere on the board
/*D10/SS gsw2 override: J2.3, R19.2; also elsewhere on the board
/*D11 IR Emitter: J2.2, R2.1; also elsewhere on the board
/A0: J1.4, R3.1
/A1: J1.5, R4.2
/A2: J1.6, R5.2
/A3: J1.7, R6.2
/A4: J1.8, R7.2
/A5: J1.9, R8.2
/A6: J1.10
/A7: J1.11
/AREF: J1.3
/D0/RX: J2.14, R9.1; also elsewhere on the board
/D1/TX: J2.15, U2.1 (1A); also elsewhere on the board
/D2 IR Receiver: J2.11, J11.5 (R); also elsewhere on the board
/D4 Extron sw1 Tx: J2.9, JP3.1 (A), U1.11 (T1IN); also elsewhere on the board
/D8 Extron sw2 Rx: J2.5, JP2.1 (A), U1.9 (R2OUT); also elsewhere on the board
/D12/MISO gsw1 override: J2.1, R17.2; also elsewhere on the board
/D13/SCK (LED): J1.1
/R1IN: J3.2, JP1.3 (B), U1.13 (R1IN)
/R2IN: J6.2, JP2.3 (B), U1.8 (R2IN)
/T1OUT: J3.3, JP3.3 (B), U1.14 (T1OUT)
/T2OUT: J6.3, JP4.3 (B), U1.7 (T2OUT)
GND: C4.2, C5.2, J1.14, J2.12, J3.5, J5.8, J6.5, J8.8, J9.1 (S), J10.1 (S), J11.1 (S), PH1.S, Q1.1 (E), R11.1, R12.1, R13.1, R14.2, R15.2, R16.1, R18.2, R20.2, U1.15 (GND), U2.2 (GND), U2.3 (2A); also elsewhere on the board
unnamed: J4.1 (S), Q1.3 (C)
unnamed: J4.2 (T), R1.2
unnamed: J5.3, R8.1, R16.2
unnamed: J5.5, R7.1, R15.1
unnamed: J5.6, R19.1, R20.1
unnamed: J5.7, R6.1, R14.1
unnamed: J8.3, R5.1, R13.2
unnamed: J8.5, R4.1, R12.2
unnamed: J8.6, R17.1, R18.1
unnamed: J8.7, R3.2, R11.2
unnamed: J9.5 (R), JP3.2 (C)
unnamed: J9.2 (T), JP1.2 (C)
unnamed: J10.5 (R), JP4.2 (C)
unnamed: J10.2 (T), JP2.2 (C)
unnamed: PH1.R, R9.2
unnamed: Q1.2 (B), R2.2
unnamed: C1.1, U1.1 (C1+)
unnamed: C1.2, U1.3 (C1-)
unnamed: C3.1, U1.4 (C2+)
unnamed: C3.2, U1.5 (C2-)
unnamed: C2.1, U1.2 (VS+)
unnamed: C4.1, U1.6 (VS-)
unnamed: PH1.T, R10.2, R21.2, U2.6 (1Y)
VCC: J1.15

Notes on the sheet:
EXTRON sw2
GSCART sw2
RT4K <- Serial
Arduino Nano
EXTRON sw1
IR Receiver
IR Emitter
alt sw2
GSCART sw1
alt sw1
All C = 0.1UF 50V X7R 0805 R1 = 30 OHM 1% 1/2W 0805 R2 = 1K OHM 1% 1/8W 0805 R3-R10, R17, R19 = 10K OHM 1% 1/8W 0805 R11-R16, R18, R20 = 20K OHM 1% 1/8W 0805

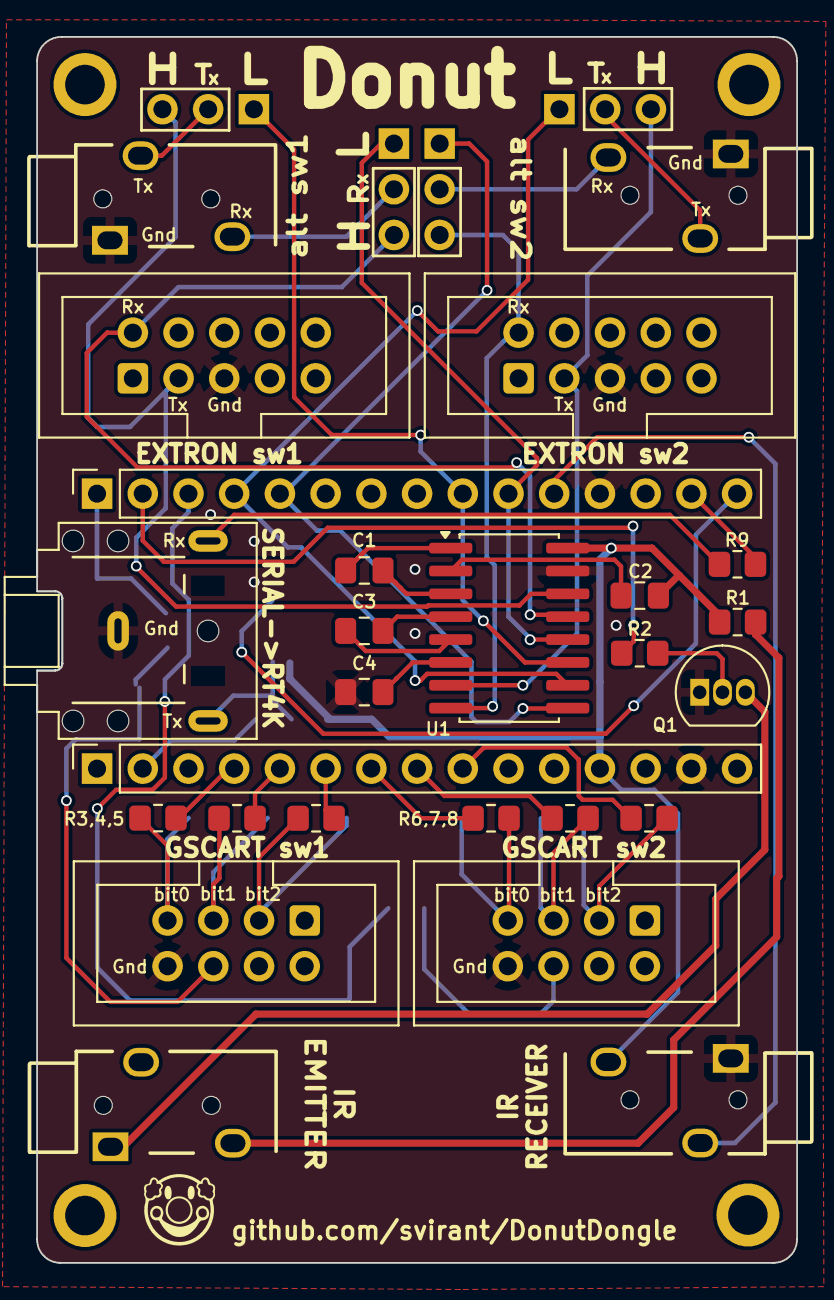
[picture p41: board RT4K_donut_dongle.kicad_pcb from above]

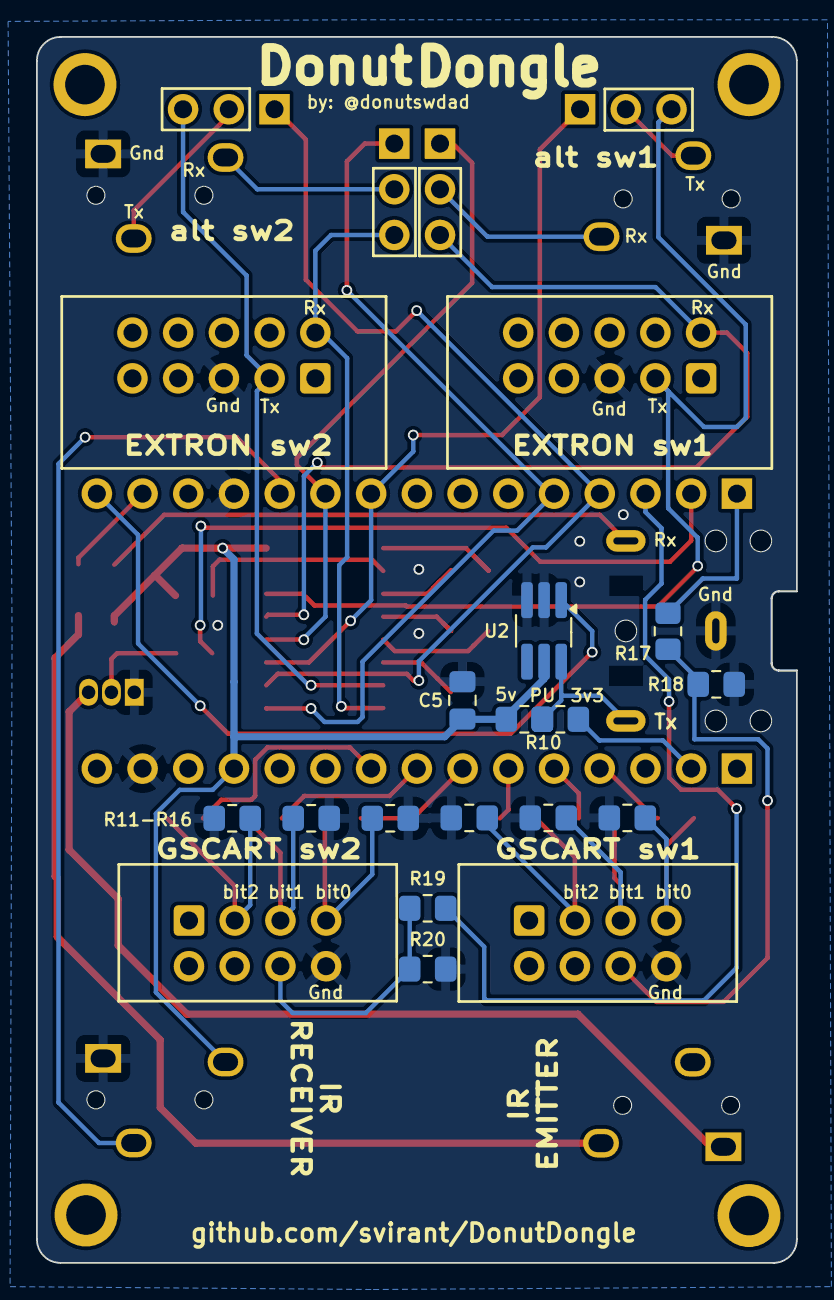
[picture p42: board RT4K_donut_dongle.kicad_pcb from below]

Board: 2 copper layers, 42.2 x 68.1 mm, 48 parts (14 on the bottom side), 46 nets.

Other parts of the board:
J1#2: 2.54mm Pitch Single Row Female 15P Header Strip; PinSocket_1x15_P2.54mm_Vertical

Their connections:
/*D3 Extron sw1 Rx: J1#2.10; also elsewhere on the board
/*D9 Extron sw2 Tx: J1#2.4; also elsewhere on the board
/*D10/SS gsw2 override: J1#2.3; also elsewhere on the board
/*D11 IR Emitter: J1#2.2; also elsewhere on the board
/D0/RX: J1#2.14; also elsewhere on the board
/D1/TX: J1#2.15; also elsewhere on the board
/D2 IR Receiver: J1#2.11; also elsewhere on the board
/D4 Extron sw1 Tx: J1#2.9; also elsewhere on the board
/D8 Extron sw2 Rx: J1#2.5; also elsewhere on the board
/D12/MISO gsw1 override: J1#2.1; also elsewhere on the board
GND: J1#2.12; also elsewhere on the board

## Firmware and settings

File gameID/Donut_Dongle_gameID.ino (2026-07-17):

/*
* Donut Dongle gameID (Arduino Nano ESP32 only)
* Copyright(C) 2026 @Donutswdad
*
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
* You should have received a copy of the GNU General Public License
* along with this program.  If not,see <http://www.gnu.org/licenses/>.
*/

#define FIRMWARE_VERSION "0.6.2a"
#define FW_TYPE 'D'
#define MAX_BYTES 50
#define MAX_EINPUT 36
#define MTV_TIME_CHECK 1500 // time between mt-viki disconnetion detection checks
#define AM_TIME_CHECK 500 // time between auto-matrix input change detection
#define SEND_LEDC_CHANNEL 0
#define IR_SEND_PIN 11  // Optional IR LED Emitter for RT5X/OSSC/TV compatibility. Sends IR data out Arduino pin D11
#define LED_BUILTIN 13
#define IR_RECEIVE_PIN 2  // Optional IR Receiver on pin D2
#define extronSerial Serial1
#define extronSerial2 Serial2
#define Serial Serial0 // ** COMMENT OUT THIS LINE ** to see output in Serial Monitor. Disables Serial output to RT4K. usbMode must also be set to "false"


#include <IRremote.hpp>
#include <TinyIRReceiver.hpp> // all can be found in the built-in Library Manager
#include <WiFi.h>
#include <WiFiClientSecure.h>
#include <HTTPClient.h>
#include <WebServer.h>
#include <LittleFS.h>
#include <ArduinoJson.h>
#include <ESPmDNS.h>
#include <ArduinoOTA.h>
#include <WiFiManager.h>
#include <Update.h>

uint8_t const debugE1CAP = 0; // line ~756
uint8_t const debugE2CAP = 0; // line ~1073
uint8_t const debugState = 0; // line ~552

////////////////////////////////////////////////////////////////////////////////////

const char* donuthostname = "donutshop";      // hostname, by default: http://donutshop.local include quotes ""

#define usbMode true              // USB Serial Command mode. set true to enable. requires OTG adapter. normal Serial mode will be active regardless of setting.

#if usbMode
#include <EspUsbHost.h> // found in the built-in Library Manager
EspUsbHost usbHost;
EspUsbHostCdcSerial CdcSerial(usbHost);
#endif

/*
////////////////////
//    OPTIONS    //
//////////////////
*/


uint16_t offset = 0; // Only needed for multiple Donut Dongles (DD). Set offset so 2nd,3rd,etc boards don't overlap SVS profiles. (e.g. offset = 300;) 
                      // MUST use SRS=1 on additional DDs. If using the IR receiver, recommended to have it only connected to the DD with lowest offset.


uint8_t SRS = 1;  // Switch Rule Set  
                      //     "Remote" profiles are profiles that are assigned to buttons 1-12 on the RT4K remote. "SVS" profiles reside under the "/profile/SVS/" directory 
                      //     on the SD card.  This option allows you to choose which ones to call when a console is powered on.  Remote profiles allow you to easily change 
                      //     the profile being used for a console's switch input if your setup is in flux. SVS require you to rename the file itself on the SD card which is 
                      //     a little more work.  Regardless, SVS profiles will need to be used for console switch inputs over 12.
                      //
                      // **** Make sure "Auto Load SVS" is "On" under the RT4K Profiles menu. A requirement for most options ****
                      //
                      // 0 - use "Remote" profiles 1-12 for up to 12 inputs on 1st Extron Switch and SVS 13 - 99 for everything over 12. Only SVS profiles are used on 2nd Extron Switch if connected.
                      //
                      //     - remote profiles 1-12 for 1st Extron or TESmart Switch (If S0 below is set to true - remote profile 12 is used when all ports are in-active)
                      //     - SVS  12 - 99  for 1st Extron or TESmart (S0 is true)
                      //     - SVS  13 - 99  for 1st Extron or TESmart (S0 is false)
                      //     - SVS 101 - 199 for 2nd Extron or TESmart
                      //
                      // 1 - use only "SVS" profiles.
                      //     Make sure "Auto Load SVS" is "On" under the RT4K Profiles menu
                      //     RT4K checks the /profile/SVS subfolder for profiles and need to be named: "S<input number>_<user defined>.rt4"
                      //     For example, SVS input 2 would look for a profile that is named S2_SNES.rt4
                      //     If there’s more than one profile that fits the pattern, the first match is used
                      //
                      //     - SVS   1 -  99 for 1st Extron or TESmart
                      //     - SVS 101 - 199 for 2nd Extron or TESmart
                      //     - SVS   0       for S0 option mentioned below
                      //
                      //  ** If S0 below is set to true, create "/profile/SVS/S0_<user defined>.rt4" for when all ports are in-active. Ex: S0_HDMI.rt4
                      //

bool S0 = false;  // (Profile 0) default is false 
                         //
                         //  ** Recommended to remove any /profile/SVS/S0_<user defined>.rt4 profiles and leave this option "false" if using in tandem with the Scalable Video Switch. **
                         //  ** Does not work with TESmart HDMI switches **
                         //
                         // set "true" to load "Remote Profile 12" instead of "S0_<user definted>.rt4" (if SRS=0) when all ports are in-active on 1st Extron switch (and 2nd if connected). 
                         // You can assign it to a generic HDMI profile for example.
                         // If your device has a 12th input, SVS will be used instead. "If" you also have an active 2nd Extron Switch, Remote Profile 12
                         // will only load if "BOTH" switches have all in-active ports.
                         // 
                         // 
                         // If SRS=1, /profile/SVS/ "S0_<user defined>.rt4" will be used instead of Remote Profile 12
                         //

////////////////////////// 
                        // Choosing the above two options can get quite confusing (even for myself) so maybe this will help a little more:
                        //
                        // when S0=0 and SRS=0, button profiles 1 - 12 are used for EXTRON sw1, and SVS for EVERYTHING else
                        // when S0=0 and SRS=1, SVS profiles are used for everything
                        // when S0=1 and SRS=0, button profiles 1 - 11 are used for EXTRON sw1 and Remote Profile 12 as "Profile S0", and SVS for everything else 
                        // when S0=1 and SRS=1, SVS profiles for everything, and uses S0_<user defined>.rt4 as "Profile 0" 
                        //
//////////////////////////

//////////////////////////////////////////////////////////////////////////////////////
// EXTRON MATRIX

uint8_t ExtronVideoOutputPortSW1 = 1; // For certain Extron Matrix models, must specify the video output port that connects to RT4K
uint8_t ExtronVideoOutputPortSW2 = 1; // can also be used for auto matrix mode as shown in next option


// For Extron Matrix switches that support DSVP. RGBS and HDMI/DVI video types.
bool automatrixSW1 = false; // set true for auto matrix switching on "SW1" port
bool automatrixSW2 = false; // set true for auto matrix switching on "SW2" port


uint8_t vinMatrix[65] = {0,  // MATRIX switchers  // When auto matrix mode is enabled: (automatrixSW1 / automatrixSW2 defined above)
                                                        // set to 0 for the auto switched input to tie to all outputs
                                                        // set to 1 for the auto switched input to trigger a Preset
                                                        // set to 2 for the auto switched input to tie to "ExtronVideoOutputPortSW1" / "ExtronVideoOutputPortSW2"
                                                        //
                                                        // For option 1, set the following inputs to the desired Preset #
                                                        // (by default each input # is set to the same corresponding Preset #)
                           1,  // input 1 SW1
                           2,  // input 2
                           3,  // input 3
                           4,  // input 4
                           5,  // input 5
                           6,  // input 6
                           7,  // input 7
                           8,  // input 8
                           9,  // input 9
                           10,  // input 10
                           11,  // input 11
                           12,  // input 12
                           13,  // input 13
                           14,  // input 14
                           15,  // input 15
                           16,  // input 16
                           17,  // input 17
                           18,  // input 18
                           19,  // input 19
                           20,  // input 20
                           21,  // input 21
                           22,  // input 22
                           23,  // input 23
                           24,  // input 24
                           25,  // input 25
                           26,  // input 26
                           27,  // input 27
                           28,  // input 28
                           29,  // input 29
                           30,  // input 30
                           30,  // input 31
                           30,  // input 32
                               //
                               // ONLY USE FOR 2ND MATRIX SWITCH on SW2
                           1,  // 2ND MATRIX SWITCH input 1 SW2
                           2,  // 2ND MATRIX SWITCH input 2
                           3,  // 2ND MATRIX SWITCH input 3
                           4,  // 2ND MATRIX SWITCH input 4
                           5,  // 2ND MATRIX SWITCH input 5
                           6,  // 2ND MATRIX SWITCH input 6
                           7,  // 2ND MATRIX SWITCH input 7
                           8,  // 2ND MATRIX SWITCH input 8
                           9,  // 2ND MATRIX SWITCH input 9
                           10,  // 2ND MATRIX SWITCH input 10
                           11,  // 2ND MATRIX SWITCH input 11
                           12,  // 2ND MATRIX SWITCH input 12
                           13,  // 2ND MATRIX SWITCH input 13
                           14,  // 2ND MATRIX SWITCH input 14
                           15,  // 2ND MATRIX SWITCH input 15
                           16,  // 2ND MATRIX SWITCH input 16
                           17,  // 2ND MATRIX SWITCH input 17
                           18,  // 2ND MATRIX SWITCH input 18
                           19,  // 2ND MATRIX SWITCH input 19
                           20,  // 2ND MATRIX SWITCH input 20
                           21,  // 2ND MATRIX SWITCH input 21
                           22,  // 2ND MATRIX SWITCH input 22
                           23,  // 2ND MATRIX SWITCH input 23
                           24,  // 2ND MATRIX SWITCH input 24
                           25,  // 2ND MATRIX SWITCH input 25
                           26,  // 2ND MATRIX SWITCH input 26
                           27,  // 2ND MATRIX SWITCH input 27
                           28,  // 2ND MATRIX SWITCH input 28
                           29,  // 2ND MATRIX SWITCH input 29
                           30,  // 2ND MATRIX SWITCH input 30
                           30,  // 2ND MATRIX SWITCH input 31
                           30,  // 2ND MATRIX SWITCH input 32
                           };

// RT4K IR remote options ////////////////////////////////////////////////////////////////////////

                           // ** Must be on firmware version 3.7 or higher **
uint8_t RT5Xir = 0;     // 0 = disables IR Emitter for RetroTink 5x
                              // 1 = enabled for Extron sw1 / alt sw1, TESmart HDMI, MT-ViKi, or Otaku Games Scart Switch if connected
                              //     sends Profile 1 - 10 commands to RetroTink 5x. Must have IR LED emitter connected.
                              //
                              // 2 = enabled for gscart switch only (remote profiles 1-8 for first gscart, 9-10 for first 2 inputs on second gscart)
                              //
                              // 3 = enabled for Extron sw2 / alt sw2, TESmart HDMI, MT-ViKi, or Otaku Games Scart Switch if connected 
                              //     sends Profile 1 - 10 commands to RetroTink 5x. Must have IR LED emitter connected.
                              //
                              // 4 = enabled for Otaku Games Scart Switch that is connected to Extron sw1 / alt sw1 with another Otaku via headphone splitter.
                              //      this 2nd Otaku has been flashed to repsond with "remote prof13" - "remote prof22", and "remote prof24" when all ports are off.

uint8_t OSSCir = 0;     // 0 = disables IR Emitter for OSSC
                              // 1 = enabled for Extron sw1 switch, TESmart HDMI, or Otaku Games Scart Switch if connected
                              //     sends Profile 1 - 14 commands to OSSC. Must have IR LED emitter connected.
                              //     
                              // 2 = enabled for gscart switch only (remote profiles 1-8 for first gscart, 9-14 for first 6 inputs on second gscart)
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
void loop(){
   // 
   // leave empty
   //
}  // end of loop()


void DDloop(void *pvParameters){
  (void)pvParameters;

  for(;;){
    #if FW_TYPE == 'D'
    readIR();
    readExtron1();
    readExtron2();
    if(RTwake && CdcSerial.connected()) sendRTwakeUSB(); // new method for usb serial. can detect when Tink is fully off/on
    else if(RTwake) sendRTwake(8000); // 8000 is 8 seconds. After waking the RT4K, wait this amount of time before re-sending the latest profile change.
    if(delaySend)DStime(500);
    #endif
    server.handleClient();
    if(debugState){
      vTaskDelay(pdMS_TO_TICKS(100));
      Serial.print(F("GAMEID1 "));Serial.print(F(" On: "));Serial.print(mswitch[GAMEID1].On);Serial.print(F(" King: "));Serial.print(mswitch[GAMEID1].King);Serial.print(F(" Prof: "));Serial.println(mswitch[GAMEID1].Prof);
      Serial.print(F("EXTRON1 "));Serial.print(F(" On: "));Serial.print(mswitch[EXTRON1].On);Serial.print(F(" King: "));Serial.print(mswitch[EXTRON1].King);Serial.print(F(" Prof: "));Serial.println(mswitch[EXTRON1].Prof);
      Serial.print(F("EXTRON2 "));Serial.print(F(" On: "));Serial.print(mswitch[EXTRON2].On);Serial.print(F(" King: "));Serial.print(mswitch[EXTRON2].King);Serial.print(F(" Prof: "));Serial.println(mswitch[EXTRON2].Prof);
    }
    else{
      vTaskDelay(pdMS_TO_TICKS(2));
    }
    ArduinoOTA.handle();
  }
} // end of DDloop

void GIDloop(void *pvParameters){
  (void)pvParameters;

  for(;;){
    readGameID();
    vTaskDelay(pdMS_TO_TICKS(5));
  }
} // end of GIDloop

void OTAsetup(){
  ArduinoOTA.setHostname(donuthostname);
  ArduinoOTA.onError([](ota_error_t error){
      Serial.printf("Error[%u]: ", error);
      if (error == OTA_AUTH_ERROR) Serial.println("OTA Auth Failed");
      else if (error == OTA_BEGIN_ERROR) Serial.println("OTA Begin Failed");
      else if (error == OTA_CONNECT_ERROR) Serial.println("OTA Connect Failed");
      else if (error == OTA_RECEIVE_ERROR) Serial.println("OTA Receive Failed");
      else if (error == OTA_END_ERROR) Serial.println("OTA End Failed");
  });
  ArduinoOTA.begin();
} // end of OTAsetup()

void readGameID(){ // queries addresses in "consoles" array for gameIDs
  currentGameTime = millis();  // Init timer
  if(prevGameTime == 0)       // If previous timer not initialized, do so now.
    prevGameTime = millis();
  if((currentGameTime - prevGameTime) >= gTime){ // make sure at least gTime has passed before continuing
    int result = 0;
    for(int i = 0; i < consolesSize; i++){
      if(WiFi.status() == WL_CONNECTED && consoles[i].Enabled){ // wait for WiFi connection
        HTTPClient http;
        WiFiClientSecure https;
        http.setConnectTimeout(2000); // give only 2 seconds per http console to check gameID, is only honored for IP-based addresses
        https.setInsecure(); // needed for MemCardPro 2.0+ firmware support
        https.setTimeout(5); // give 5 seconds for https 
        https.setHandshakeTimeout(5); // ^^^
        if(consoles[i].Address.substring(0,5) == "https") http.begin(https,consoles[i].Address);
        else http.begin(consoles[i].Address);
        analogWrite(LED_BLUE,222);
        int httpCode = http.GET();             // start connection and send HTTP header
        if(httpCode > 0 || httpCode == -11){   // httpCode will be negative on error, let the read error slide...
          if(httpCode == HTTP_CODE_OK){        // console is healthy // HTTP header has been sent and Server response header has been handled
            consoles[i].Address = replaceDomainWithIP(consoles[i].Address); // replace Domain with IP in consoles array. this allows setConnectTimeout to be honored
            payload = http.getString();        
            JsonDocument doc;
            DeserializationError error = deserializeJson(doc, payload);
            if(!error){ // If the response is JSON, continue
              if(!doc["gameID"].isNull()) {  // If payload contains gameID, 
                payload = doc["gameID"].as<String>(); // reset payload to it's value
              }
            }
            result = fetchGameIDProf(payload,consoles[i].DefaultProf);
            consoles[i].On = 1;
            if(consoles[i].Prof != result && result != -1){ // gameID found for console, set as King, unset previous King, send profile change 
              consoles[i].Prof = result;
              consoles[i].King = 1;
              uint8_t prevOrder = consoles[i].Order;
              for(int j=0;j < consolesSize;j++){ // set Order, set previous King to 0
                if(j == i){
                  consoles[j].Order = 0;
                  consoles[j].King = 1;
                }
                else{
                  consoles[j].King = 0;
                  if(consoles[j].Order < prevOrder) consoles[j].Order++;
                }
              }
              sendProfile(consoles[i].Prof,GAMEID1,0);
            }
          } 
        } // end of if(httpCode > 0 || httpCode == -11)
        else{ // console is off, set attributes to 0, find lowest Order console that is On, set as King, send profile
          consoles[i].On = 0;
          consoles[i].Prof = 0;
          if(consoles[i].King == 1){
            int bestIdx = -1;
            uint8_t bestO = consolesSize;
            for(uint8_t j=0;j < consolesSize;j++){
              if(consoles[j].On && consoles[j].Order < bestO){
                bestO = consoles[j].Order;
                bestIdx = j;
              }
            }
            for(uint8_t k=0;k < consolesSize;k++){
              consoles[k].King = 0;
            }
            if(bestIdx != -1){ 
              consoles[bestIdx].King = 1;
              sendProfile(consoles[bestIdx].Prof,GAMEID1,0);
              return;
            }
          } // end of if(consoles[i].King == 1)
          int count = 0;
          for(int m=0;m < consolesSize;m++){
            if(consoles[m].On == 0) count++;
          }
          if(count == consolesSize){
            sendProfile(0,GAMEID1,1);
          }
        } // end of else()
      http.end();
      analogWrite(LED_BLUE, 255);
      }  // end of WiFi connection
      else if(!consoles[i].Enabled){ // console is disabled in web ui, set attributes to 0, find lowest Order console that is On, set as King, send profile
        consoles[i].On = 0;
        consoles[i].Prof = 0;
        if(consoles[i].King == 1){
          int bestIdx = -1;
          uint8_t bestO = consolesSize;
          for(uint8_t j=0;j < consolesSize;j++){
            if(consoles[j].On && consoles[j].Order < bestO){
              bestO = consoles[j].Order;
              bestIdx = j;
            }
          }
          for(uint8_t k=0;k < consolesSize;k++){
            consoles[k].King = 0;
          }
          if(bestIdx != -1){ 
            consoles[bestIdx].King = 1;
            sendProfile(consoles[bestIdx].Prof,GAMEID1,0);
            return;
          }
        } // end of if(consoles[i].King == 1)
      } // end of if else()
    }
    currentGameTime = 0;
    prevGameTime = 0;
  }
}  // end of readGameID()

uint8_t readAMstate(String& sinput, uint8_t size){

  uint32_t newAMstate = 0;
  for(uint8_t i=0;i < size;i++){
    char c = sinput.charAt(i);
    if(c >= '1' && c <= '9'){
      newAMstate |= (1UL << (size - 1 - i));
    }
  }

  uint32_t changed = newAMstate ^ prevAMstate;

  for(uint8_t bitPos = 0;bitPos < size;bitPos++){
    uint32_t bit = 1UL << (size - 1 - bitPos);
    uint8_t input = bitPos + 1;
    if(changed & bit){
      if(newAMstate & bit){ // input on
        bool exists = false;
        for(int j=0;j <= AMstateTop;j++){
          if(AMstate[j] == input){
            exists = true;
            break;
          }
        }
        if(!exists && AMstateTop < (size - 1)) AMstate[++AMstateTop] = input;
      } // end of input on
      else{ // input off
        for(int j=0;j <= AMstateTop;j++){
          if(AMstate[j] == input){
            for(int k = j;k < AMstateTop;k++){
              AMstate[k] = AMstate[k + 1];
            }
            AMstateTop--;
            break;
          }
        }
      } // end of input off
    } // end of changed ?
  } // end of for

  prevAMstate = newAMstate;
  return AMstate[AMstateTop];
} // end of readAMstate()


String readTink(){
  if(CdcSerial.available() > 0){
    return CdcSerial.readString();
  }
  else if(Serial.available() > 0){
    return Serial.readString();
  }
  else return "";
} // end of readTink()
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

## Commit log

2025-01-03 create Adapters
    [YC2VGA_shorty-BOM.csv]
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2025-01-04 BOM moved to README
    [BOM-donut_dongle.csv]
2025-01-05 10k pull-down resistors for gscart has shown to be too high, 1k should work better
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2025-01-08 fixed DP0 edge-case
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2025-01-11 IR remote receiver: increased rate at which left and right directional buttons move when held down
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2025-01-15 fixed assembly graphic typo
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2025-01-18 gussie fail, reg style BOM update lol
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2025-01-22 updated dual Extron DP0 logic. follows that of gscart and otaku. now it's much easier to add new switches
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2025-01-23 added Preset support for Extron Matrix Switches. Confirmed firsthand on DXP 88
2025-01-23 MT-VIKI 8 port HDMI switch support added. RT4K remote can also change inputs w/ AUX8 + profile button 1 - 8
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2025-02-05 waking RT4K with remote will also resend the current profile after it's finished waking
2025-02-05 blink builtin led while waking RT4K from sleep (ability to cancel wake)
2025-02-05 blink builtin led while waking RT4K from sleep (revert ability to cancel)
    [RT4K_donut_dongle.ino]
2025-02-06 renamed function, fixed RT4K IR S0_ logic
    [RT4K_donut_dongle.ino]
2025-02-07 fixed gscart S0_ bug, arranged const variables
    [RT4K_donut_dongle.ino]
2025-02-07 AUX8 + Power button can power cycle a TV via IR emitter
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2025-02-28 gscart / gcomp manual input selection verified working for vers 5.x switches, must enable with gctl = 1
2025-03-12 RC2 DD pcb released. No major changes, RC1 can easily be modified. See Assembly section.
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2025-03-13 RC2 updated KiCad files
    [RT4K_donut_dongle.kicad_pcb, RT4K_donut_dongle.kicad_sch]
2025-03-13 updated RC2 info
    [RT4K_donut_dongle.kicad_sch]
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2025-03-20 added "return" character before every serial command to clear out buffer. needed when sharing TX bus with other devices.
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2025-04-11 added VGA Passthrough adapter case
    [VGAPassthrough bottom.3MF, VGAPassthrough top.3MF]
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2025-07-09 MT-VIKI / Extron / DB9 to 3.5mm adapter added. DIY instead of buying the pricey Amazon version.
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2025-07-09 added 3DP housing for MT-VIKI / Extron / DB9 to 3.5mm adapter
    [DB9-35mm.3mf]
2025-07-11 updated to have supports enabled by default
    [DB9-35mm.3mf]
2025-07-11 updated supports
    [DB9-35mm.3mf]
2025-07-14 fixed bug where auto matrix mode on SW2 sent same profiles as SW1
    [Donut_Dongle_beta.ino]
2025-07-15 fixed Presets sometimes not being detected. auto switching can now be set to output to ALL outputs.
    [Donut_Dongle_beta.ino]
2025-07-15 previous Presets bug should now also be fixed for matrix switches that report In00 vs In0
    [Donut_Dongle_beta.ino]
2025-07-16 fixed voutMatrix bug. now in auto matrix mode, all input ties to output(s) are cleared when input inactive
    [Donut_Dongle_beta.ino]
2025-07-16 fixed logic in setTie() so that it only removes the ties it creates
    [Donut_Dongle_beta.ino]
2025-07-18 more memory tweaks, fixed setTie bug leftover from downsizing to 16 from 32 input/outputs
    [Donut_Dongle_beta.ino]
2025-07-22 fixed bug in auto matrix mode preventing S0 profile from being sent in certain scenarios
    [Donut_Dongle_beta.ino]
2025-08-12 IR code for LG TV power button should now be more compatible with other LG TVs
2025-08-15 HUGE! Thanks to Arthrimus, MT-VIKI face/remote buttons now send profiles. Enable "MTVbuttons" in .ino
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2025-10-02 updated Bambu Studio settings for higher quality print
    [DB9-35mm.3mf]
2025-10-22 bug found in MT-VIKI face button logic that would cause sw2 to also respond even when not being used
    [Donut_Dongle_beta.ino]
2025-10-22 fixed bug where wrong profile would be sent when waking the RT4K and using an offset
    [Donut_Dongle_beta.ino]
2025-10-22 updated with only one wall on top surfaces in slicer
    [DB9-35mm.3mf]
2025-10-23 updated BOM to potentially help with "hot plugging" 3.5mm rs-232 connections. not recommended, can lockup max3232 IC
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2025-10-27 updated remote receiver to respond to AUX4 = Color Correction menu shortcut, AUX5 = Audio menu shortcut. If using "gctl = 1" to manually change gscart/comp switch inputs, Press "AUX5" twice for Audio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
    [RT4K_donut_dongle.ino]
2025-10-27 updated remote receiver to respond to AUX4 = Color Correction menu shortcut, AUX5 = Audio menu shortcut. If using "gctl = 1" to manually change gscart/comp switch inputs, Press "AUX5" twice for Audio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
    [Donut_Dongle_beta.ino]
2025-11-20 reverted to previous reliable method of power toggle for LG CX OLED
    [Donut_Dongle_gameID.ino]
2026-01-18 merged back in Auto_Matrix_beta and added support for older Extron Crosspoint switches
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2026-01-18 alternate format for 3D printing services
    [DB9-35mm.stl]
2026-01-18 fixed output port capture for older Extron Crosspoints
    [Donut_Dongle_beta.ino]
2026-01-18 fixed command sent when "RECONFIG" is received from Extron switchers
    [Donut_Dongle_beta.ino]
2026-01-19 fixed bug where older Extron Crosspoints wouldnt be able to switch from input 1 to 11. moved "RECONFIG" response into its own function.
    [Donut_Dongle_beta.ino]
2026-01-20 moving voutMatrix out of SRAM broke compatibility with some switches.
    [Donut_Dongle_beta.ino]
2026-01-21 rewrote functions to be PROGMEM compatible. fixed bug in automatrix mode.
    [Donut_Dongle_beta.ino]
2026-01-21 consolidated mt-viki and tesmart serial commands now use less SRAM. fixed bug in mt-viki disconnection detection where an input change via the Tink remote wouldn't stick.
    [Donut_Dongle_beta.ino]
2026-01-24 http://donutshop.local when clicking "Add Profile" the current gameID will automatically populate the field.
2026-01-25 added ability to turn off checking consoles for gameID. each console in the list is checked for 2 seconds before moving on to the next one. uncheck powered off ones to speed up the loop.
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2026-01-30 potential fix for mt-viki regression lockup bug
    [Donut_Dongle_beta.ino]
2026-02-04 when all consoles are off on a switch, will change profiles back to the another switch that still has active consoles. can fallback to/from SW1, SW2, GSCART1, GSCART2
2026-02-04 when all consoles are off on SW1, will change profiles back to SW2 if there are active consoles and vice versa. Switches most report when they have no active connections for this feature to work.
2026-02-04 gameID is now part of the "fallback" system, which is where when all inputs are off on a switch, or no gameIDs can be found, a profile change to the previous connected switch with an active input wil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
2026-02-05 fixed some edge cases with GAMEID profile changes
    [Donut_Dongle_gameID.ino]
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2026-02-07 This update prevents the "S0" or "remote prof12" profile from constantly overriding any profile loaded with the remote when all consoles are off and S0 set true.
    [Donut_Dongle_gameID.ino]
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2026-02-07 fallback keeps track of switch order. currentProf now stores "remote button profiles" as negative numbers.
2026-02-10 OTA updates are now available over Wifi in Arduino IDE 2.x. donutshop will now show up as a network port in "Ports". wifi / creds have moved to the top of file. other minor tweaks.
2026-02-11 USB Serial Host mode can now be used instead to send Serial Commands. set "usbMode" to true. requires additional library and OTG adapter. fixed wake/sleep for usb mode.
    [Donut_Dongle_gameID.ino]
2026-02-12 fixed a bug where when S0 = true, profiles changed with the IR remote would not stick
    [Donut_Dongle_beta.ino]
2026-02-12 Revert "fixed a bug where when S0 = true, profiles changed with the IR remote would not stick"
    This reverts commit 0cf3e879c8b327efd93b7ba7adfe6eab3a124fdf.
    [Donut_Dongle_beta.ino]
2026-02-12 fixed a MT-VIKI bug where when S0 = true, profiles changed with the IR remote would not stick
    [Donut_Dongle_beta.ino]
2026-02-12 begin merging of DonutShop .ino code to have a single Project that does both.
    Standalone acts just like current DonutShop project. Place the Nano ESP32 into a Donut Dongle board and you have the features of both! This does however remove the GSCART functionality due to the pin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
    Web UI upon first boot will be identical to the DonutShop project's. If you connect it to a DD board and it sees a connected switch, it removes the S0_pwr_profile portion of the Web UI and the S0 opt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
2026-02-13 accidental double press of aux8 + power button also toggles tv power. usb serial commands now also end with a \r\n like HD-15 serial. reverted project merge changes for now.
    [Donut_Dongle_gameID.ino]
2026-02-17 import/export now saves settings as well.builtin red led now also flickers when profile has been sent. moved Add Consoles/Profiles button. cosmetic updates in web ui.
2026-02-18 automatically sets automatrix switch to Verbose 3 if the switch reboots. double press of AUX8 + Power button also sends IR to power toggle a TV.
    [Donut_Dongle_beta.ino]
2026-02-18 usbHost mode now on by default. controlled by "#define usbMode". Serial continues to work over VGA. Automatically sets Extron Matrix Switch in autoswitch mode to Verbose 3 if it reboots.
    [Donut_Dongle_gameID.ino]
2026-02-18 WifiManager now in charge of Wifi settings. No more entering your credentials in the .ino! Upon first power up connect to "DonutShop_Setup" Wifi AP to join to your network. OTA password has been remo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
2026-02-18 Firmware Update now possible in Web UI. Added support for 12 port Extron Matrix switches to automatically enable Verbose 3 mode when in automatrix mode. Now supports 8, 12, 16, 24 & 32 port Extron Ma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
2026-02-18 Added support for 12 port Extron Matrix switches to automatically enable Verbose 3 mode when in automatrix mode.
2026-02-19 added support for MCP 2.0+ firmware devices. fixed hostname for new WifiManager.
    [Donut_Dongle_gameID.ino]
2026-02-19 fixed sendSVS command over VGA Serial when usbMode = true. added new Mode so same code base can be used for DonutShop project and hide irrelevant settings.
    [Donut_Dongle_gameID.ino]
2026-02-24 gameID consoles now fallback in the order in which they were powered on. removed delays in certain functions.
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2026-03-01 fixed long standing bug that would have caused changing inputs on the MT-VIKI via RT4K remote to not work in certain scenarios
    [Donut_Dongle_beta.ino, Donut_Dongle_gameID.ino]
2026-03-13 fixed regression bug for Extron switches that respond with single digit input. Ex: "In1 " vs "In01"
    [Donut_Dongle.ino]
2026-03-13 fixed regression bug for Extron switches that respond with single digit input. Ex: "In1 " vs "In01". Uptime is now shown when hovering over "Current Version" in Firmware Update section.
    [Donut_Dongle_gameID.ino]
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2026-04-24 fixed? webserver crashing scenario
    [Donut_Dongle_gameID.ino]
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2026-04-25 SAFE button has replaced AUX8 button when used to change auxprof with the IR remote. MT-VIKI control options have been updated.
    [Donut_Dongle.ino]
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2026-06-05 added simple Telnet server. added RT4K Terminal in "Settings" section of DonutShop. (Remote Control Commands are relayed to RT4K) Navigation of the RT4K menu is possible with keyboard keys. Replaced 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
    [Donut_Dongle_gameID.ino]
2026-06-19 in keyboard nav mode, undefined keys no longer reside in prompt.
    [Donut_Dongle_gameID.ino]
2026-07-08 fixed bug where Alternate SVS Profiles would not load when using usb-c serial
    [Donut_Dongle_gameID.ino]
2026-07-16 AUX5 now loads previous profile. Great for A/B profile comparisons. Feature is also available in the RT4K Terminal. Removed "SVS CURRENT INPUT=#" part of the command sequence. Not needed and makes A/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
    [Donut_Dongle_gameID.ino]
2026-07-17 fixed bug for when "remote pwr" or "pwr on" commands were sent consecutively, the web interface would lockup
    [Donut_Dongle_gameID.ino]
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

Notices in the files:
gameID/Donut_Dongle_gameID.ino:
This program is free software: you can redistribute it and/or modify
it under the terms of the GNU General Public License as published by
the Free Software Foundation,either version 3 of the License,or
